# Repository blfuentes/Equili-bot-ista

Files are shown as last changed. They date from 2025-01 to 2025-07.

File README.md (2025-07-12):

# Project of Self-balancing bot 'Equili-bot-ista'
The 'Equili-bot-ista' / 'Roborracho' / 'Robotis Yeltsin' is a self-balancing robot which tries to keeb standing and can be controlled with a joystick control and wields a spear.

## Technologies
- ESP32 with ESP-IDF framework
- C++

## Functionalities
- Self balancing robot
- Two modes: Fighting and Footing (Spear position)
- Drive can be remotely controlled
- Adjustment of PID on the go with remote control

## Demo
### Robot

https://github.com/user-attachments/assets/f29adb14-0a24-4408-b29b-bd193cecef2e

### Control

https://github.com/user-attachments/assets/a7362dce-cef8-4407-b584-1fbcb6137070

## Media
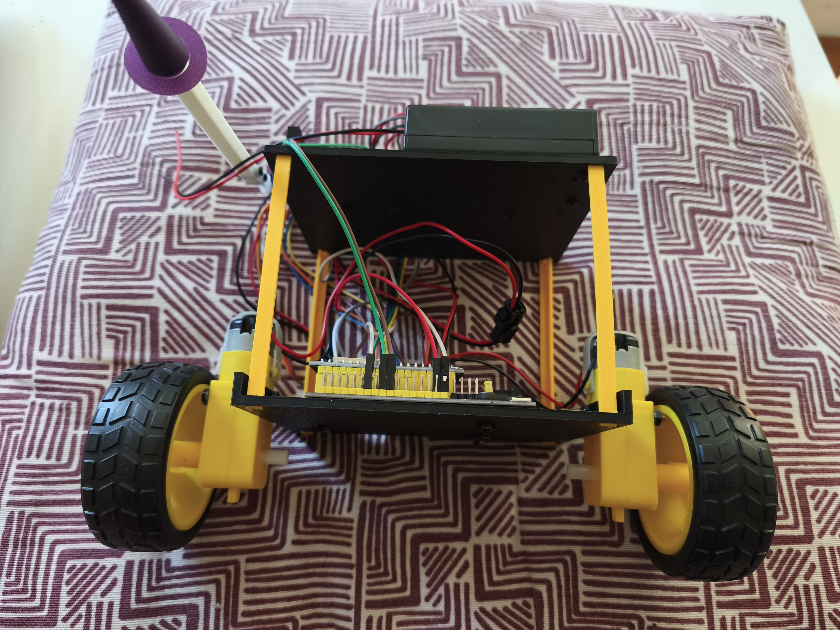
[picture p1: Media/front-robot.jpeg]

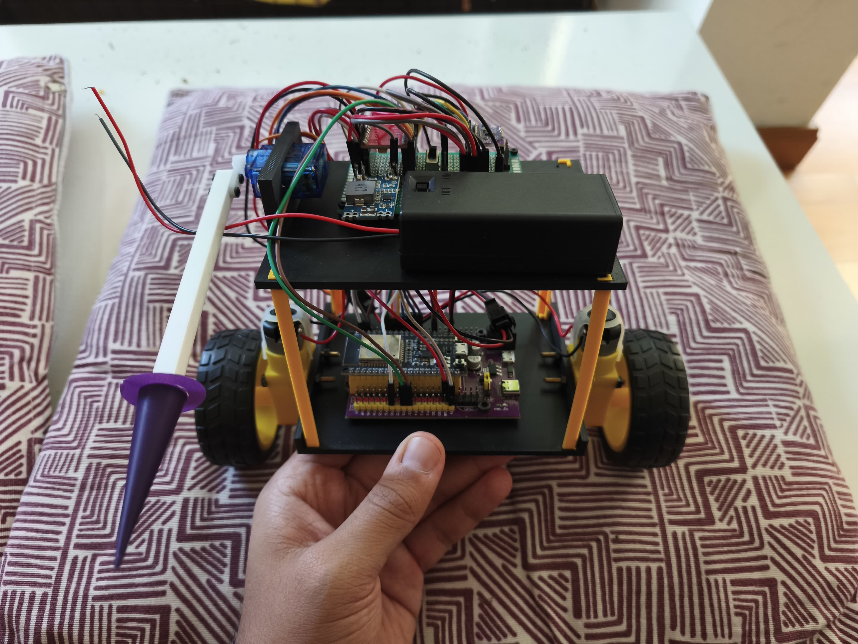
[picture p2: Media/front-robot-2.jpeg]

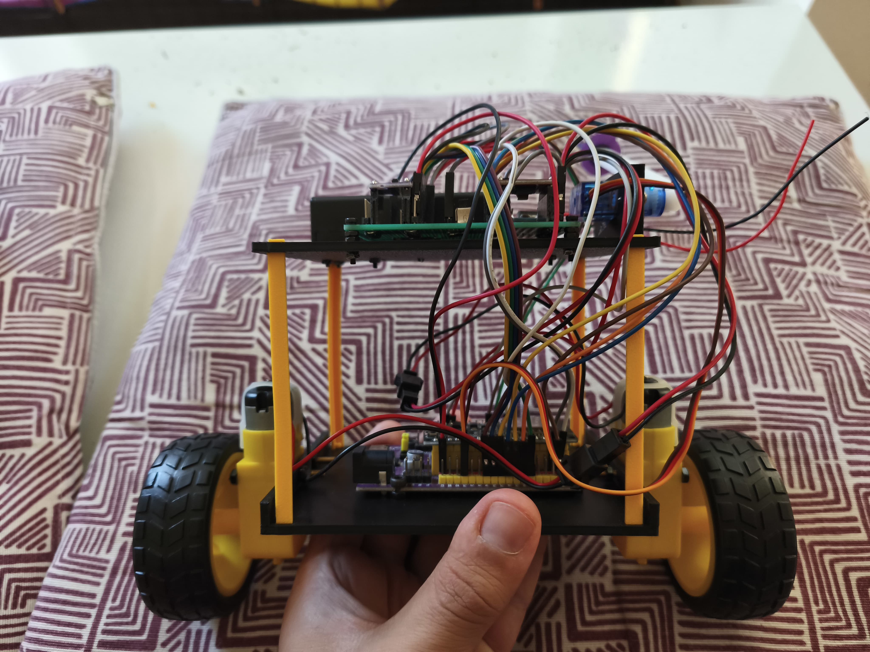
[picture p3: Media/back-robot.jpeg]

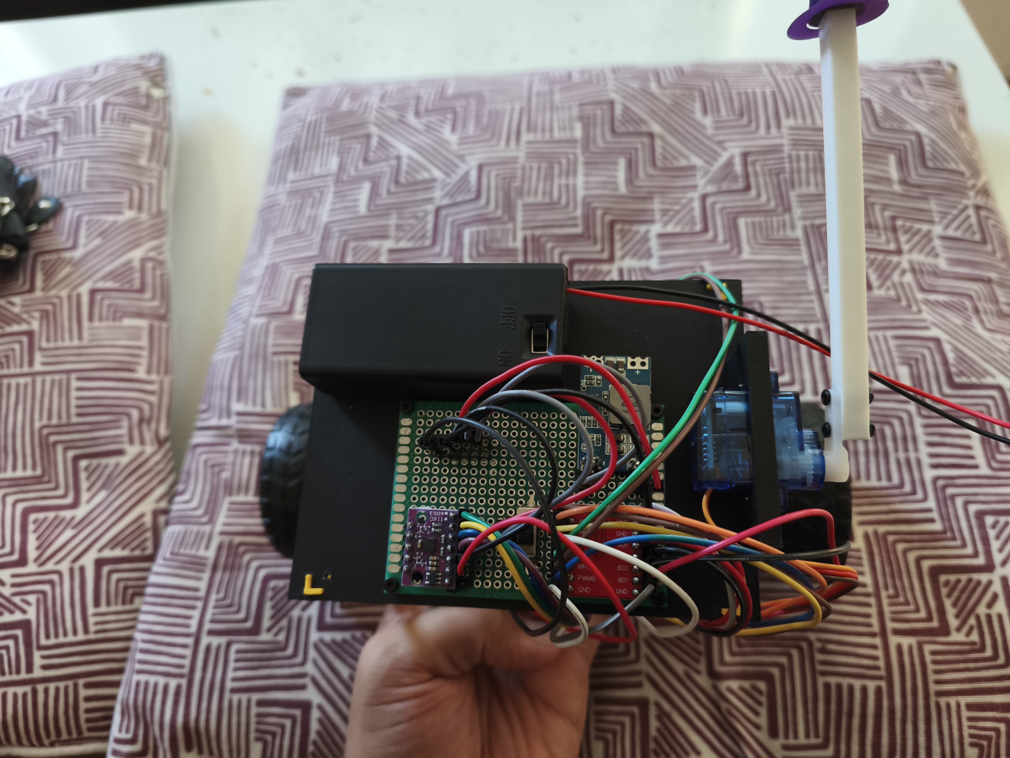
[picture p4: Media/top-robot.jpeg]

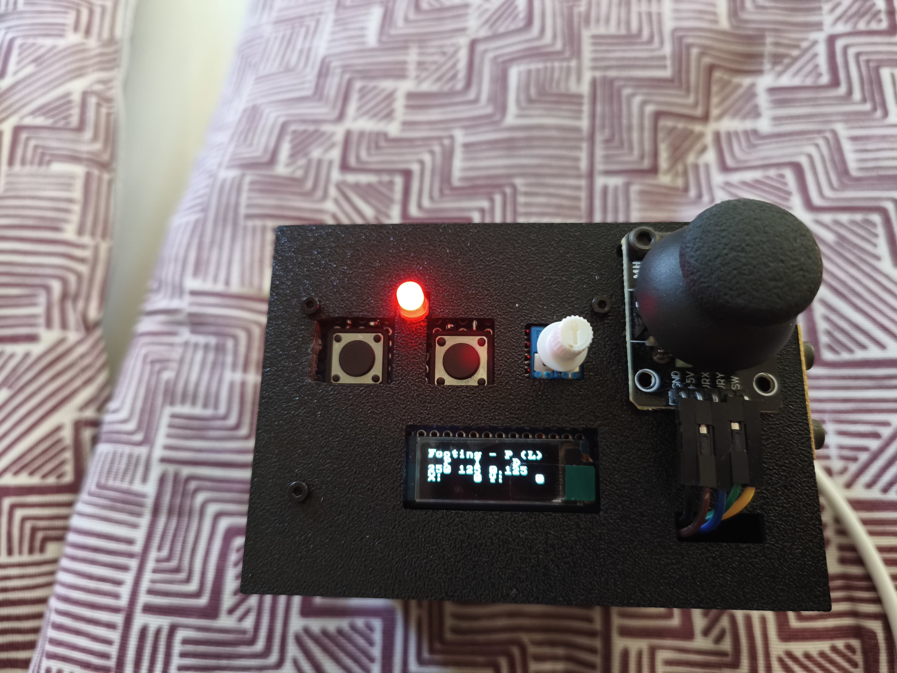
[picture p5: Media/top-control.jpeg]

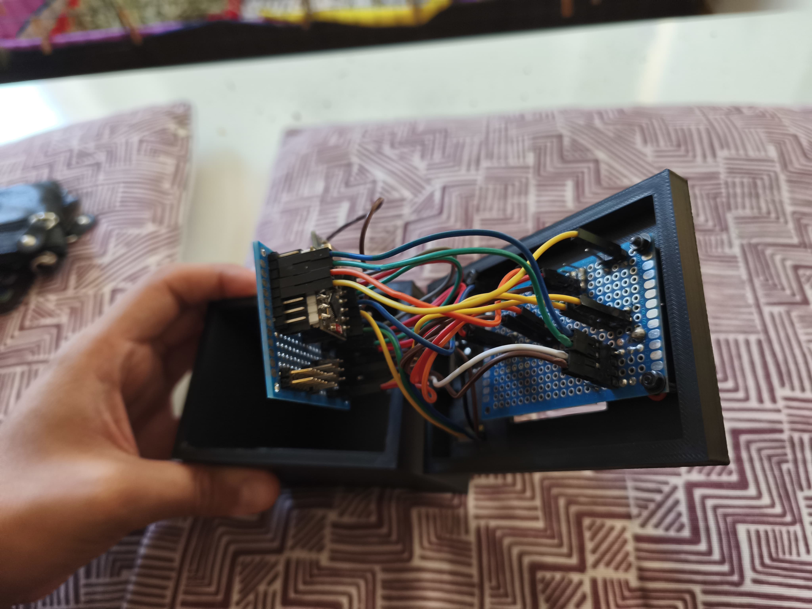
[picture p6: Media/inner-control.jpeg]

## Schema
### Main robot
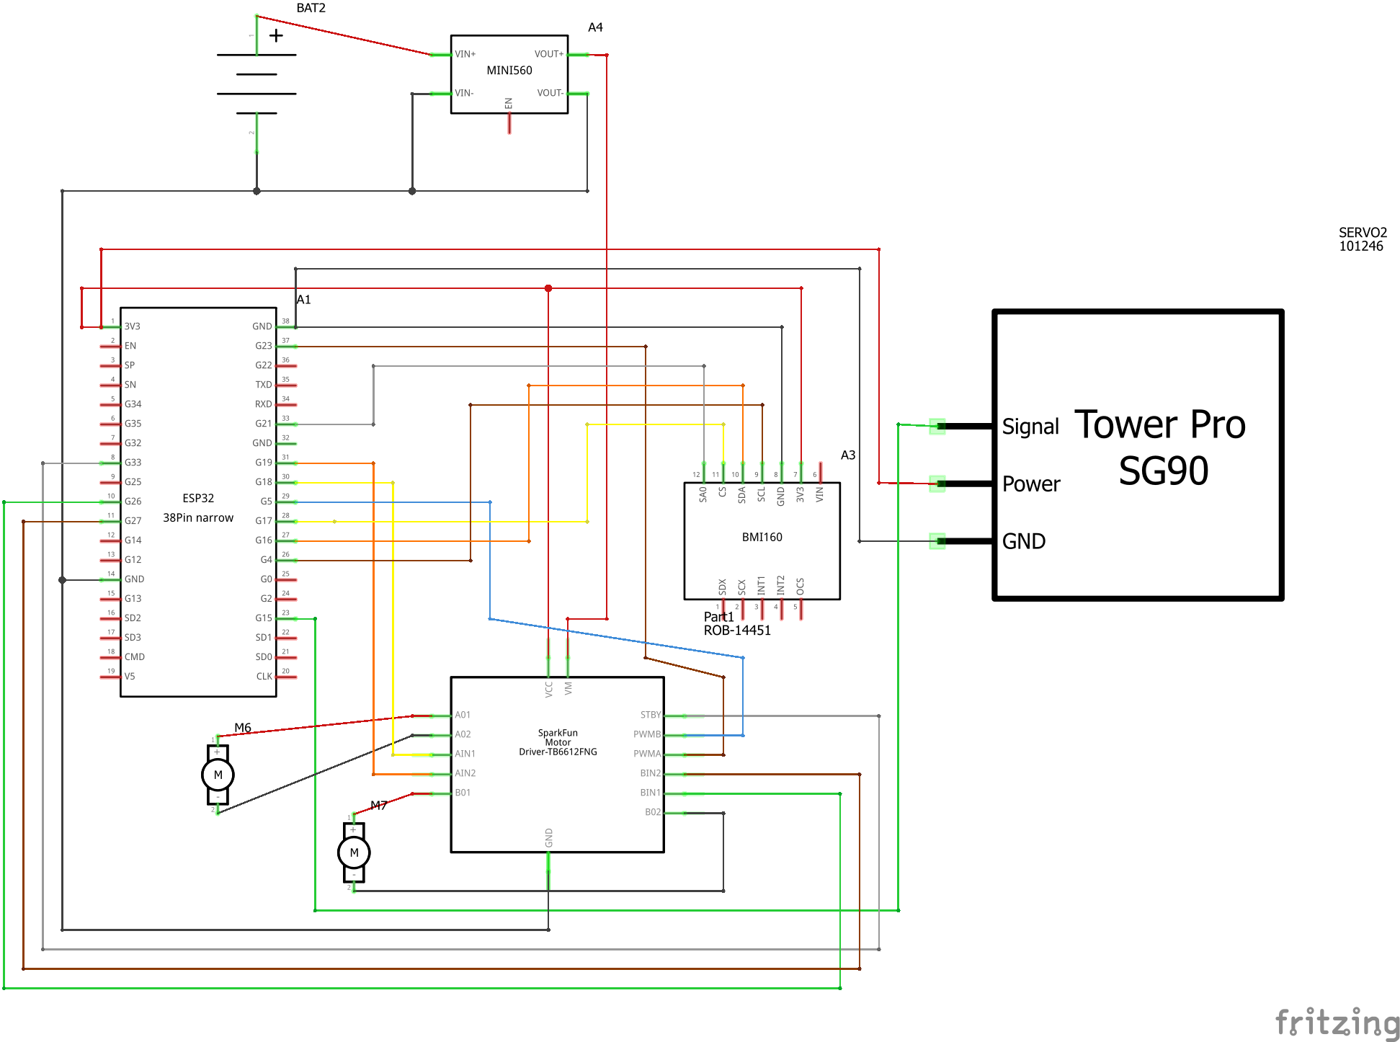
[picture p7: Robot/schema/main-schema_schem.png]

### Control
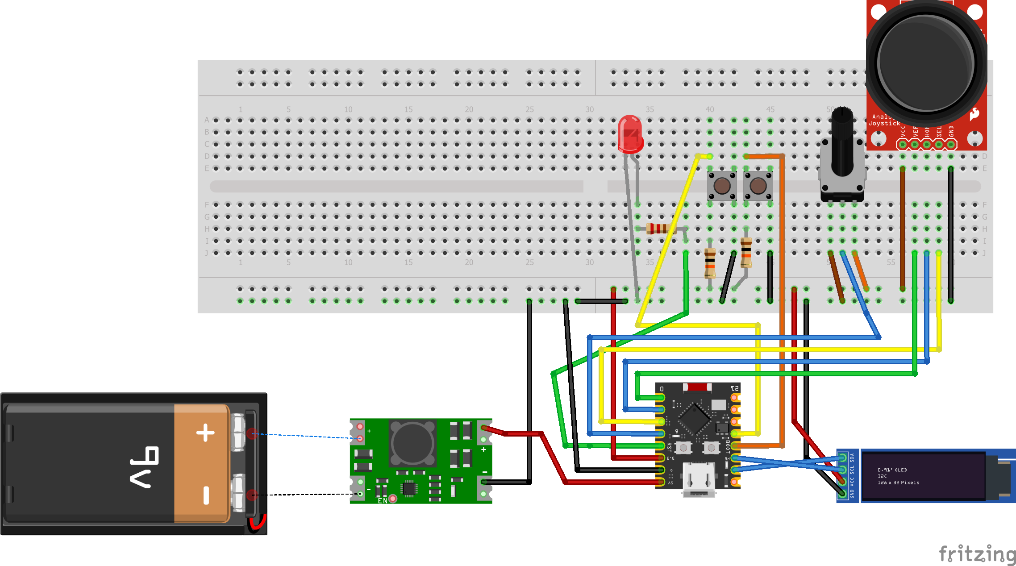
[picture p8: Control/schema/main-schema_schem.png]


## Class diagram
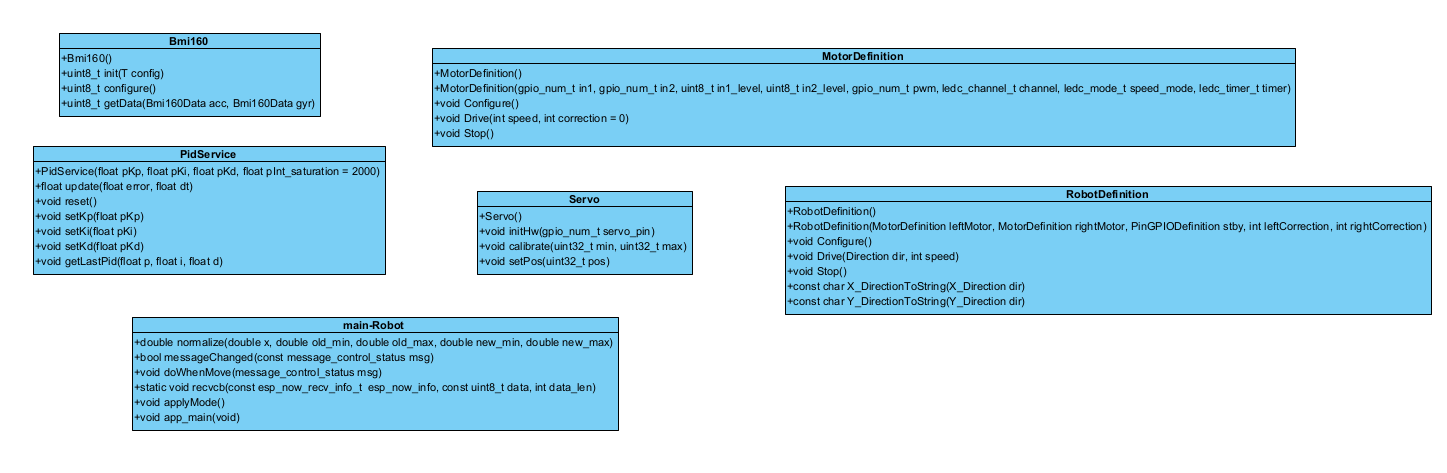
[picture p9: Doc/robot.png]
robot

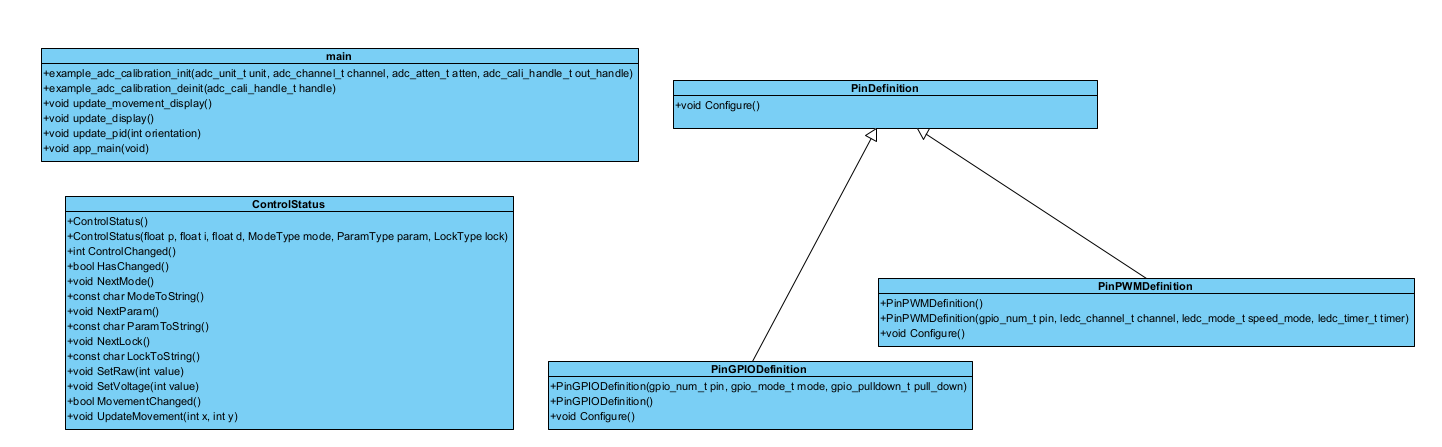
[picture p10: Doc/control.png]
control

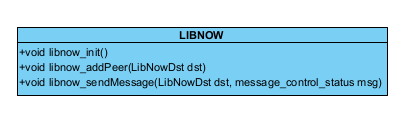
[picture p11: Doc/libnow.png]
libnow


Guided by:
https://github.com/LaboratorioGluon

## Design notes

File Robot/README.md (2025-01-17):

# Project of Self-balancing bot 'Equili-bot-ista'
## Technologies
- ESP32 with ESP-IDF framework
- C++

### Demo

### Schema
![]()
### Class diagram
![]()

Guided by:
https://github.com/LaboratorioGluon

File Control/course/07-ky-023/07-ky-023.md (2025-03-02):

```
#include <freertos/FreeRTOS.h>
#include <freertos/task.h>
#include <driver/gpio.h>
#include <driver/adc.h>
#include <esp_log.h>

// Logger tag for ESP-IDF logging
static const char * MAIN_TAG = "app_main";

extern "C" void app_main();

#define JOYSTICK_X ADC1_CHANNEL_6 // GPIO34
#define JOYSTICK_Y ADC1_CHANNEL_7 // GPIO35
#define BUTTON GPIO_NUM_32

void app_main(void)
{
    vTaskDelay(pdMS_TO_TICKS(1000));

    // Configure ADC
    esp_err_t ret;
    ret = adc1_config_width(ADC_WIDTH_BIT_12);
    if (ret != ESP_OK) {
        ESP_LOGE(MAIN_TAG, "Failed to configure ADC width: %s", esp_err_to_name(ret));
    }
    ret = adc1_config_channel_atten(JOYSTICK_X, ADC_ATTEN_DB_12);
    if (ret != ESP_OK) {
        ESP_LOGE(MAIN_TAG, "Failed to configure ADC channel X attenuation: %s", esp_err_to_name(ret));
    }
    ret = adc1_config_channel_atten(JOYSTICK_Y, ADC_ATTEN_DB_12);
    if (ret != ESP_OK) {
        ESP_LOGE(MAIN_TAG, "Failed to configure ADC channel Y attenuation: %s", esp_err_to_name(ret));
    }

    // Configure button with pull-down
    gpio_config_t io_conf;
    io_conf.intr_type = GPIO_INTR_DISABLE; // Disable interrupt
    io_conf.mode = GPIO_MODE_INPUT;       // Set as input
    io_conf.pin_bit_mask = (1ULL << BUTTON); // GPIO pin
    io_conf.pull_down_en = GPIO_PULLDOWN_DISABLE; // Disable pull-down
    io_conf.pull_up_en = GPIO_PULLUP_ENABLE;      // Enable pull-up
    ret = gpio_config(&io_conf);

    // Check if GPIO configuration was successful
    if (ret != ESP_OK) {
        ESP_LOGE(MAIN_TAG, "Failed to configure button GPIO: %s", esp_err_to_name(ret));
    } else {
        ESP_LOGI(MAIN_TAG, "Button GPIO configured successfully");
    }

    printf("KY-023 Joystick Test\n");

    for(;;)
    {
        int x_value = adc1_get_raw(JOYSTICK_X);
        int y_value = adc1_get_raw(JOYSTICK_Y);
        int button_state = gpio_get_level(BUTTON);
        printf("X: %d, Y: %d, Button: %d - %s\n", x_value, y_value, button_state, button_state ? "Not Pressed" : "Pressed");
        vTaskDelay(pdMS_TO_TICKS(100)); // Reduced delay for more responsive readings
    }
}
```

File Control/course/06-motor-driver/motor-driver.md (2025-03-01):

```
#include <freertos/FreeRTOS.h>
#include <freertos/task.h>
#include <driver/gpio.h>
#include <driver/ledc.h>
#include <esp_log.h>

#include <MotorControl.h>

// Logger tag for ESP-IDF logging
static const char * MAIN_TAG = "app_main";

// motor pins
constexpr gpio_num_t MOTOR_A_IN_1 = GPIO_NUM_18;
constexpr gpio_num_t MOTOR_A_IN_2 = GPIO_NUM_19;
constexpr gpio_num_t MOTOR_A_PWM = GPIO_NUM_23;

constexpr gpio_num_t MOTOR_B_IN_1 = GPIO_NUM_26;
constexpr gpio_num_t MOTOR_B_IN_2 = GPIO_NUM_27;
constexpr gpio_num_t MOTOR_B_PWM = GPIO_NUM_5;

constexpr gpio_num_t STBY = GPIO_NUM_33;

constexpr ledc_mode_t LEDC_SPEED_MODE = LEDC_LOW_SPEED_MODE;

MotorDefinition leftMotor;
MotorDefinition rightMotor;
PinGPIODefinition stby;

extern "C" void app_main();

void app_main(void)
{
    vTaskDelay(pdMS_TO_TICKS(1000));

    leftMotor = MotorDefinition(MOTOR_A_IN_1, MOTOR_A_IN_2, 0, 1, MOTOR_A_PWM, LEDC_CHANNEL_0, LEDC_SPEED_MODE, LEDC_TIMER_0);
    rightMotor = MotorDefinition(MOTOR_B_IN_1, MOTOR_B_IN_2, 1, 0, MOTOR_B_PWM, LEDC_CHANNEL_1, LEDC_SPEED_MODE, LEDC_TIMER_1);

    stby = PinGPIODefinition(STBY, GPIO_MODE_OUTPUT, GPIO_PULLDOWN_DISABLE);

    leftMotor.Configure();
    rightMotor.Configure();
    stby.Configure();

    gpio_set_level(STBY, 1);

    if (false)
    {
        ESP_LOGE(MAIN_TAG, "Failed to initialize bmi160 device");
    }
    else
    {
        for(;;)
        {
            leftMotor.Drive(100);
            vTaskDelay(pdMS_TO_TICKS(200));
            leftMotor.Stop();

            vTaskDelay(pdMS_TO_TICKS(1000));

            rightMotor.Drive(100);
            vTaskDelay(pdMS_TO_TICKS(200));
            rightMotor.Stop();
            
            vTaskDelay(pdMS_TO_TICKS(1000));
        }
    }
}

```

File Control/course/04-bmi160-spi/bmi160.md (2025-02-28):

```
#include <bmi160_wrapper.h>

Bmi160<Bmi160SpiConfig> imu;
gpio_num_t mosi_pin = GPIO_NUM_23;
gpio_num_t miso_pin = GPIO_NUM_19;
gpio_num_t sclk_pin = GPIO_NUM_18;
gpio_num_t cs_pin   = GPIO_NUM_21;

void app_main(void)
{
    Bmi160SpiConfig config = {
        .spidev = SPI3_HOST,
        .mosi = mosi_pin,
        .miso = miso_pin,
        .sclk = sclk_pin,
        .cs   = cs_pin,
        .speed= 4*1000*1000
    };

    if (imu.init(config) != BMI160_OK)
    {
        ESP_LOGE(MAIN_TAG, "Failed to initialize bmi160 device");
    }
    else
    {
        Bmi160Data accel_data, gyro_data;
        for(;;)
        {
            imu.getData(accel_data, gyro_data);

            printf("Raw-Accl: %6d %6d %6d\n", accel_data.raw_data.x, accel_data.raw_data.y, accel_data.raw_data.z);
            printf("Adj-Accl: %.2f %.2f %.2f\n", accel_data.adj_data.x, accel_data.adj_data.y, accel_data.adj_data.z);
            printf("Raw-Gyro: %6d %6d %6d\n", gyro_data.raw_data.x, gyro_data.raw_data.y, gyro_data.raw_data.z);
            printf("Adj-Gyro: %.2f %.2f %.2f\n", gyro_data.adj_data.x, gyro_data.adj_data.y, gyro_data.adj_data.z);

            vTaskDelay(pdMS_TO_TICKS(1000));
        }
    }
}
```

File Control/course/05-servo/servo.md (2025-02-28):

```
#include <servo.h>

Servo myServo;
gpio_num_t servo_pin = GPIO_NUM_15;

void app_main(void)
{
    vTaskDelay(pdMS_TO_TICKS(1000));

    myServo.initHw(servo_pin);
    uint32_t angle = 50;
    bool increasing = false;

    for(;;)
    {
        // Set the servo position
        myServo.setPos(angle);

        // Update the angle
        if (increasing) {
            angle++;
            if (angle >= 180) {
                increasing = false; // Reverse direction
            }
        } else {
            angle--;
            if (angle <= 0) {
                increasing = true; // Reverse direction
            }
        }

        vTaskDelay(pdMS_TO_TICKS(10));
    }
}
```

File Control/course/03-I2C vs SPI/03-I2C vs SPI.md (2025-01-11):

# I2C vs SPI

## Communication Type

| Feature | I2C | SPI |
|---|---|---|
| Type | Multi-master, multi-slave | Single-master or multi-slave |
| Connections | Two-wire (SDA, SCL) | Four-wire (MOSI, MISO, SCLK, CS) |

- I2C uses fewer pins, making it more suitable for simpler designs with |multiple devices on the same bus.
- SPI requires more pins but offers higher performance.

## Speed

|Feature | I2C | SPI |
|---|---|---|
|Typical Speed | Up to 400 kHz (standard mode), 3.4 MHz (high-speed mode) | Up to 80 MHz (ESP32 supports high clock speeds) |

- I2C is slower, making it suitable for low-speed peripherals like sensors.
- SPI is significantly faster, ideal for high-speed peripherals like displays or memory chips.

## Data Transfer
|Feature | I2C | SPI
|---|---|---|
|Data Transfer | Half-duplex | Full-duplex |

- I2C is half-duplex, meaning data transfer occurs in one direction at a time.
- SPI supports full-duplex communication, enabling simultaneous data transfer in both directions.

## Device Addressing

| Feature | I2C | SPI |
|---|---|---|
|Device Selection | Uses 7-bit or 10-bit addresses | Uses chip select (CS) lines |

- I2C relies on device addresses for communication, so fewer pins are required.
- SPI uses dedicated CS lines, requiring one CS pin per device.

## Power Consumption
| Feature | I2C | SPI |
|---|---|---|
| Power Usage | Lower (less active circuitry) | Higher (higher clock rates) |

- I2C typically consumes less power due to lower speeds.
- SPI may consume more power at high speeds but allows more efficient data transfer.

## Complexity

| Feature | I2C | SPI |
|---|---|---|
| Complexity | Simpler to wire, but requires software handling for addressing and bus arbitration | More pins and wiring complexity but straightforward data transfer protocol |

## Use Cases
| Feature | I2C | SPI |
|---|---|---|
| Best For | Low-speed devices like sensors, RTCs, small EEPROMs | High-speed devices like LCDs, flash memory, ADCs, DACs |

## Summary Table
| Feature | I2C | SPI |
|---|---|---|
| Pins Required | 2 | 4 (minimum) |
| Speed | Slower | Faster |
| Duplex | Half-duplex | Full-duplex |
| Device Count | Many devices (addressable) | Limited by CS pins |
| Best For | Low-speed peripherals | High-speed peripherals |

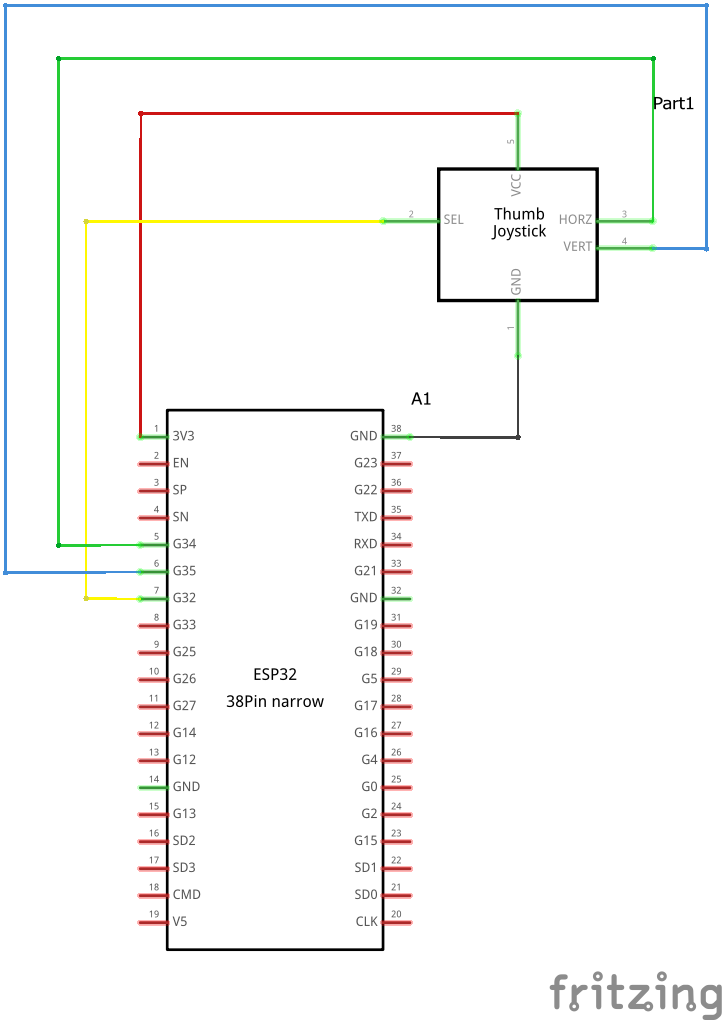
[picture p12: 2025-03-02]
Control/course/07-ky-023/schema/07-ky-023_schem.png

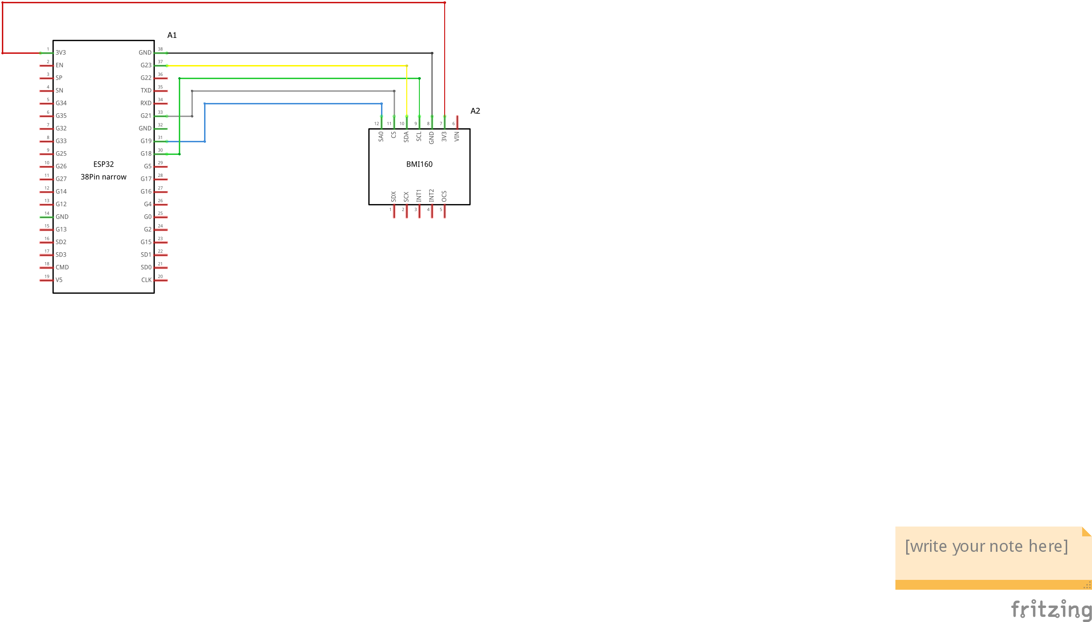
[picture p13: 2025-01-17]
Robot/course/04-bmi160-spi/Schema/04-bmi16-schema_schem.png

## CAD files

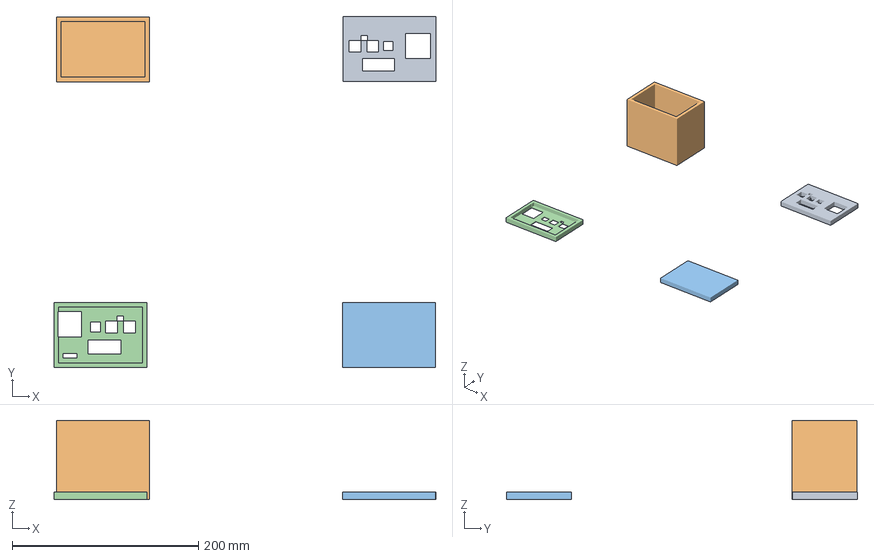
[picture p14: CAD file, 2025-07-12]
3D-Chase/Control.3mf
410.6 x 377.7 x 85.0 mm
Assembly

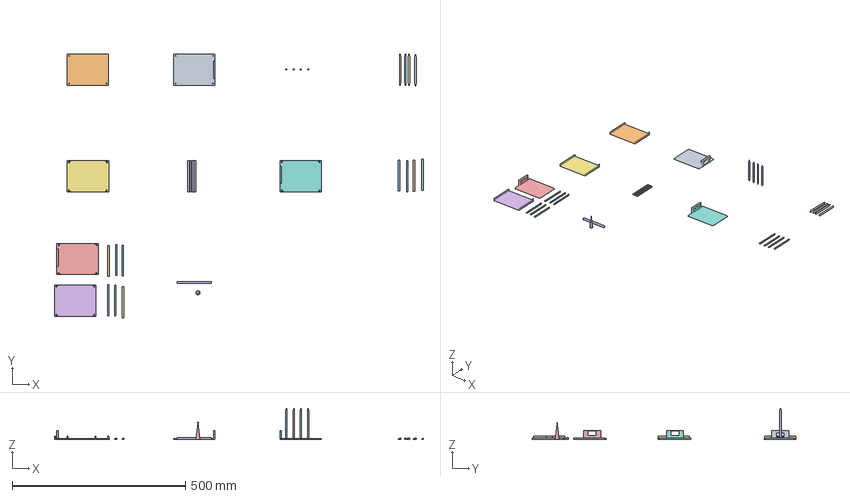
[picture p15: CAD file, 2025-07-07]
3D-Chase/Equili-bot-ista.3mf
1064.5 x 761.1 x 90.0 mm
Top
Base
Assembly x 18

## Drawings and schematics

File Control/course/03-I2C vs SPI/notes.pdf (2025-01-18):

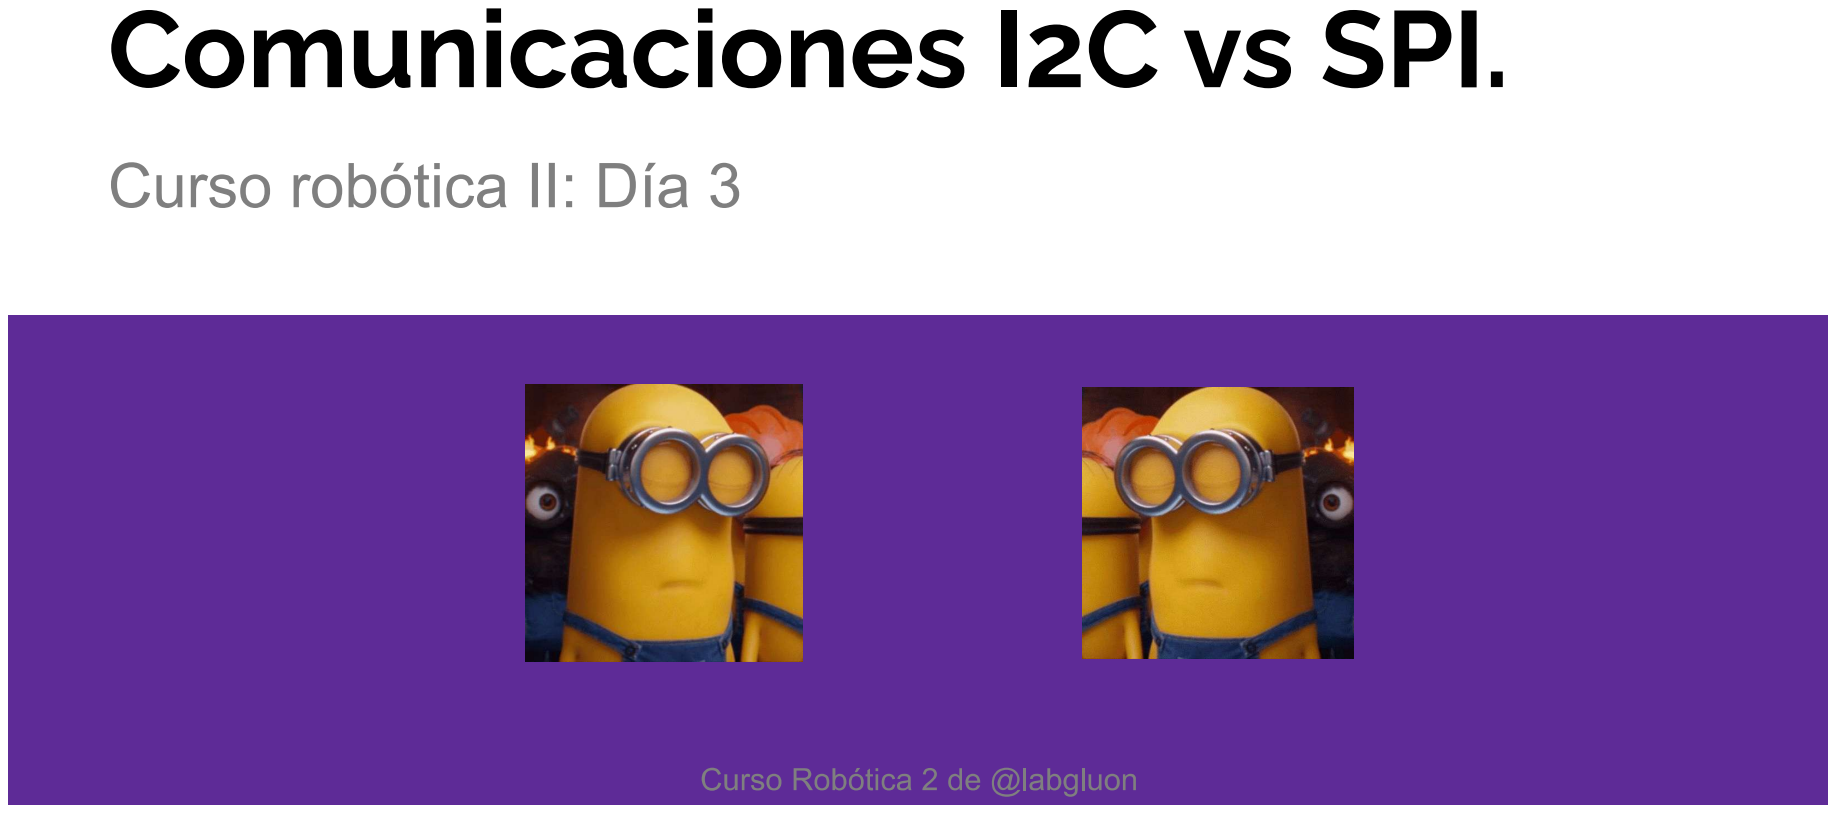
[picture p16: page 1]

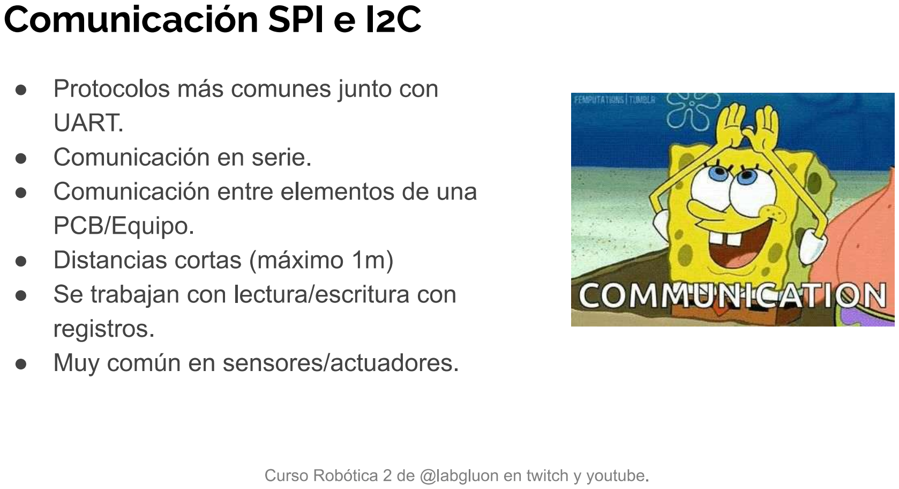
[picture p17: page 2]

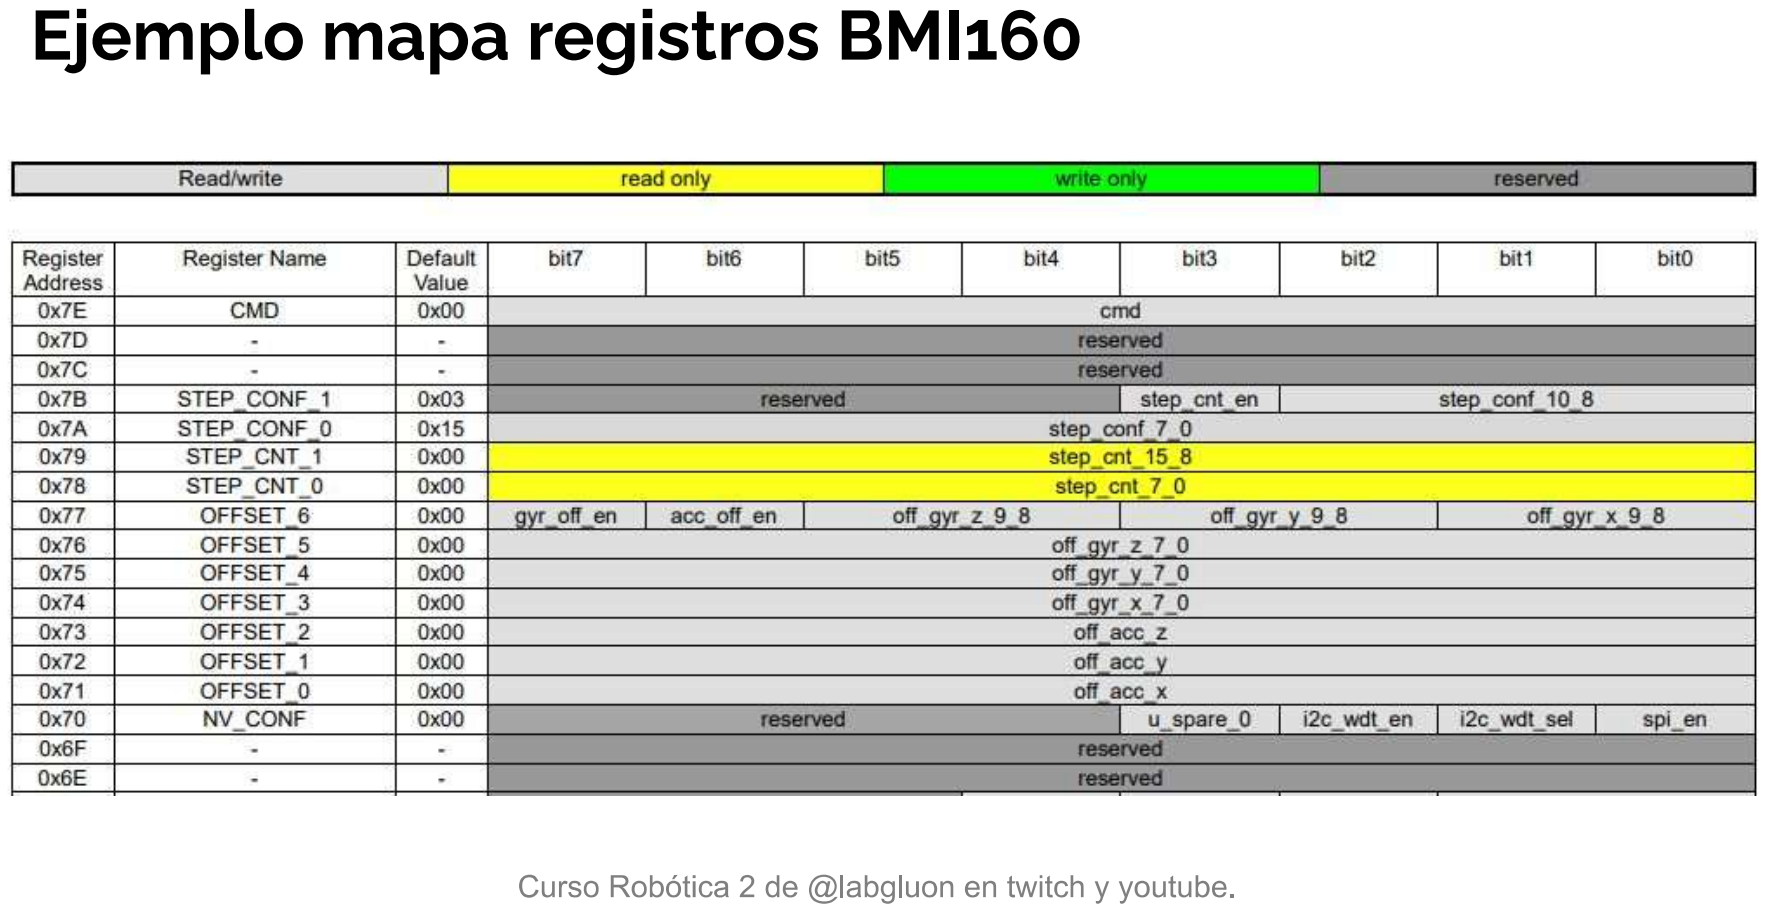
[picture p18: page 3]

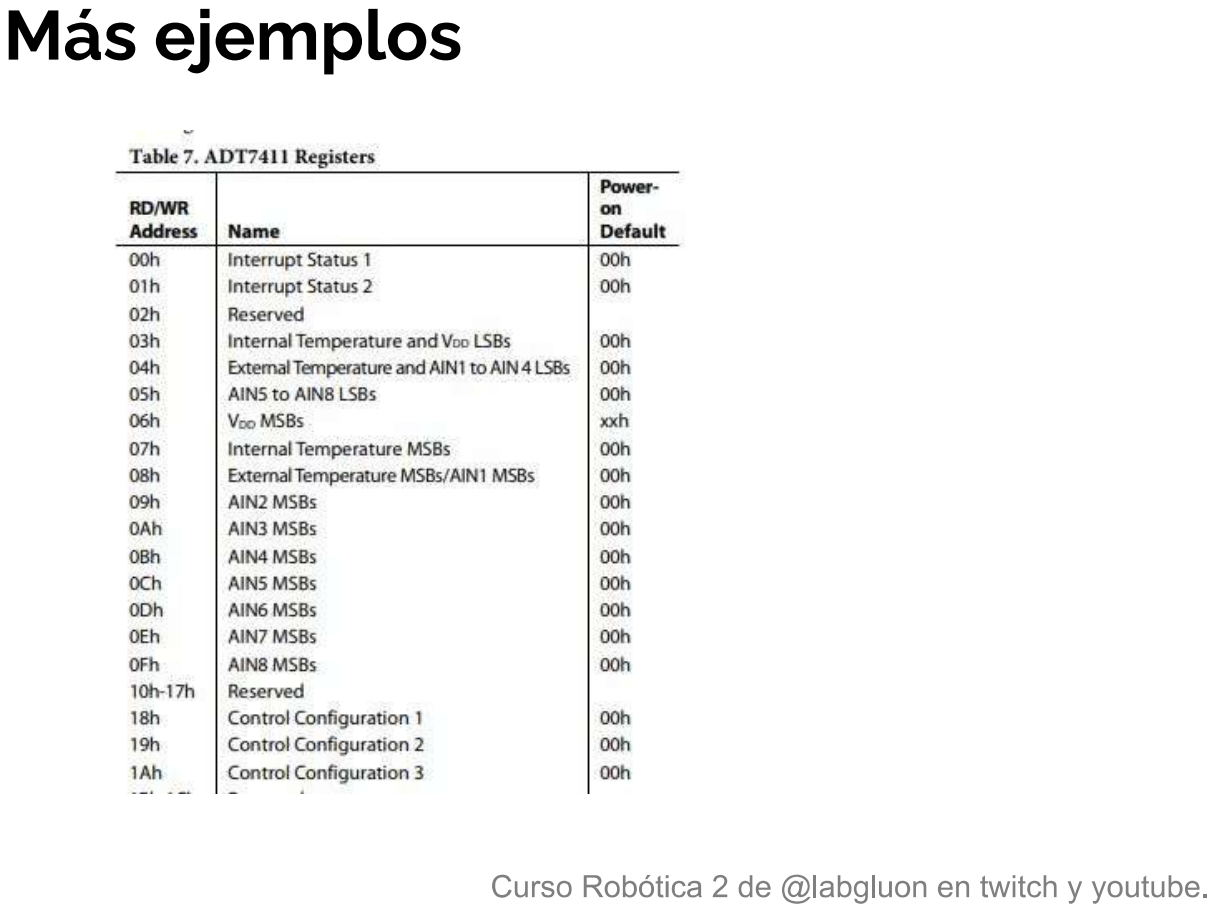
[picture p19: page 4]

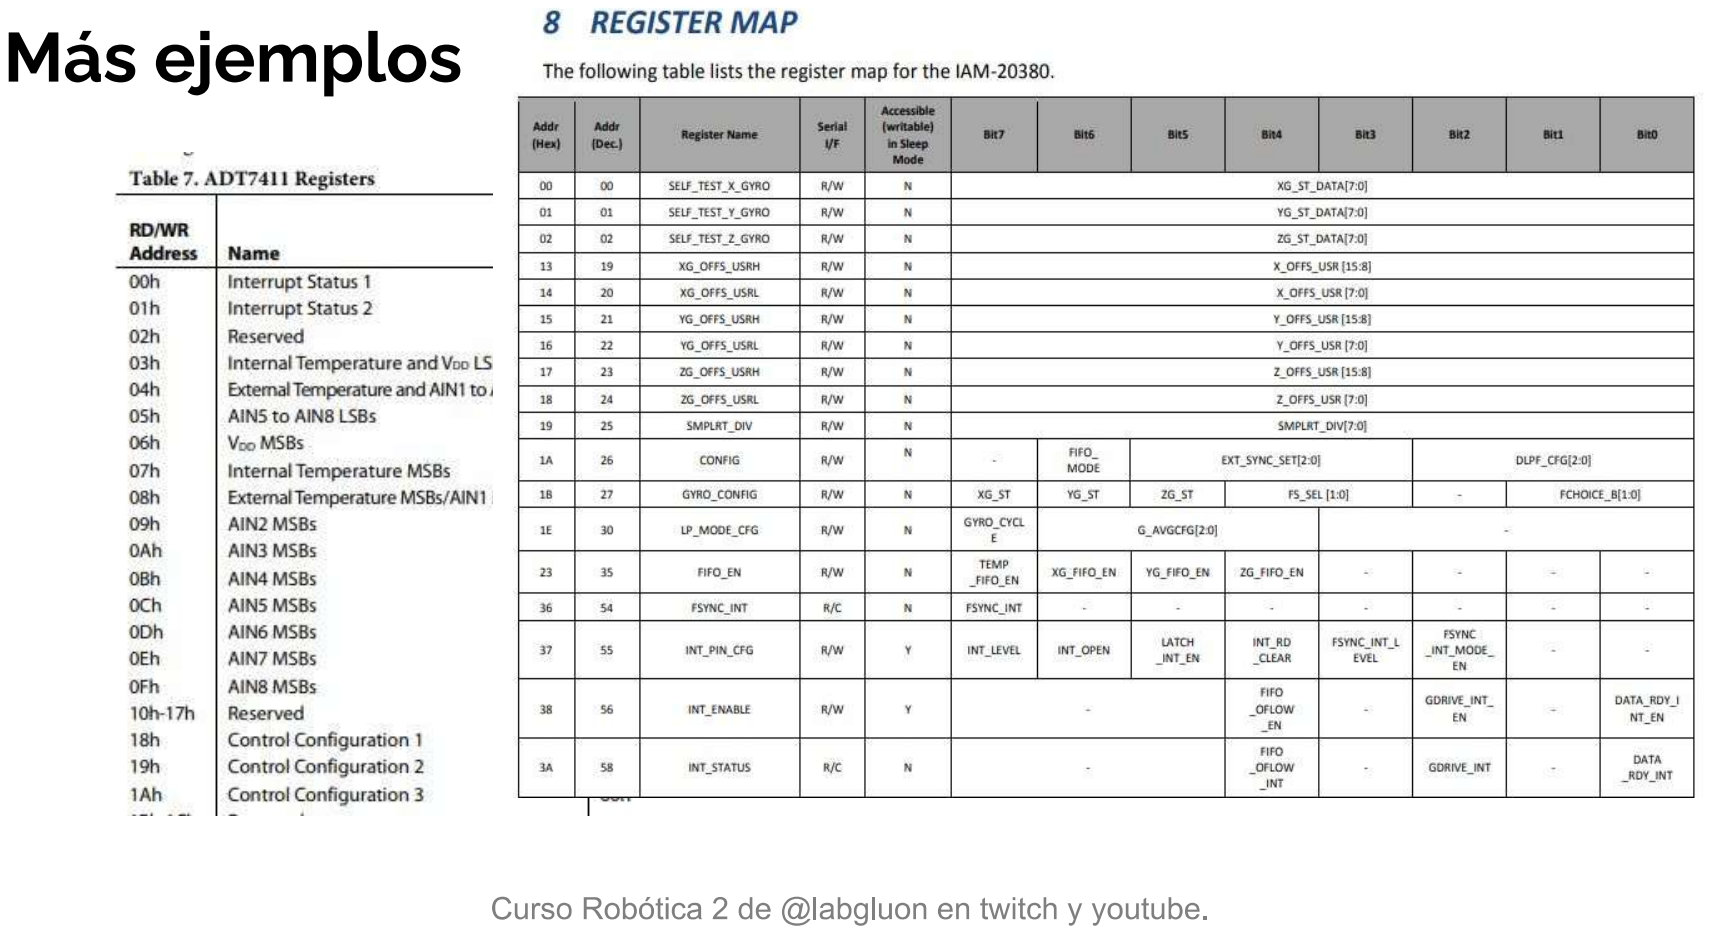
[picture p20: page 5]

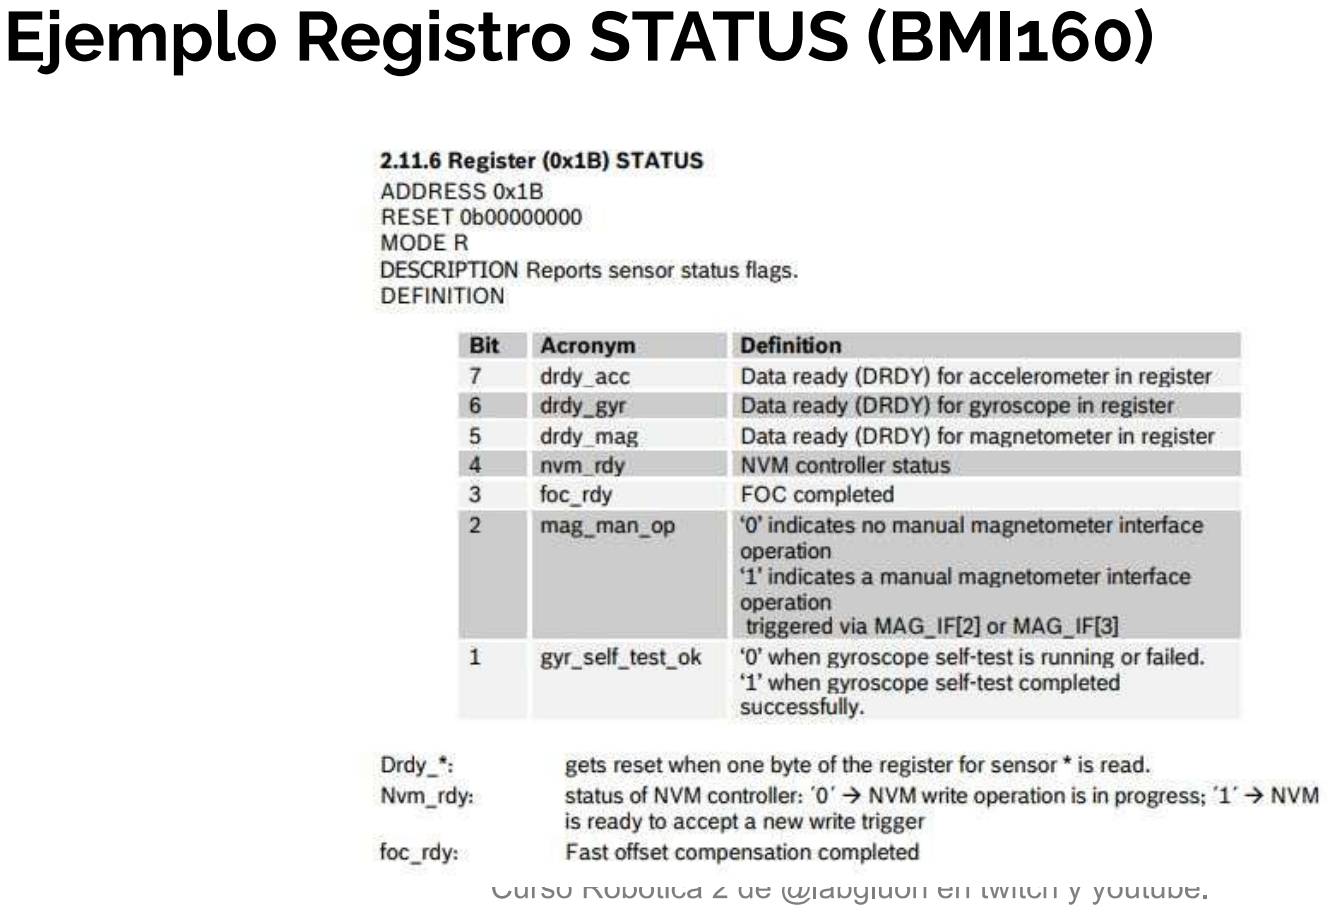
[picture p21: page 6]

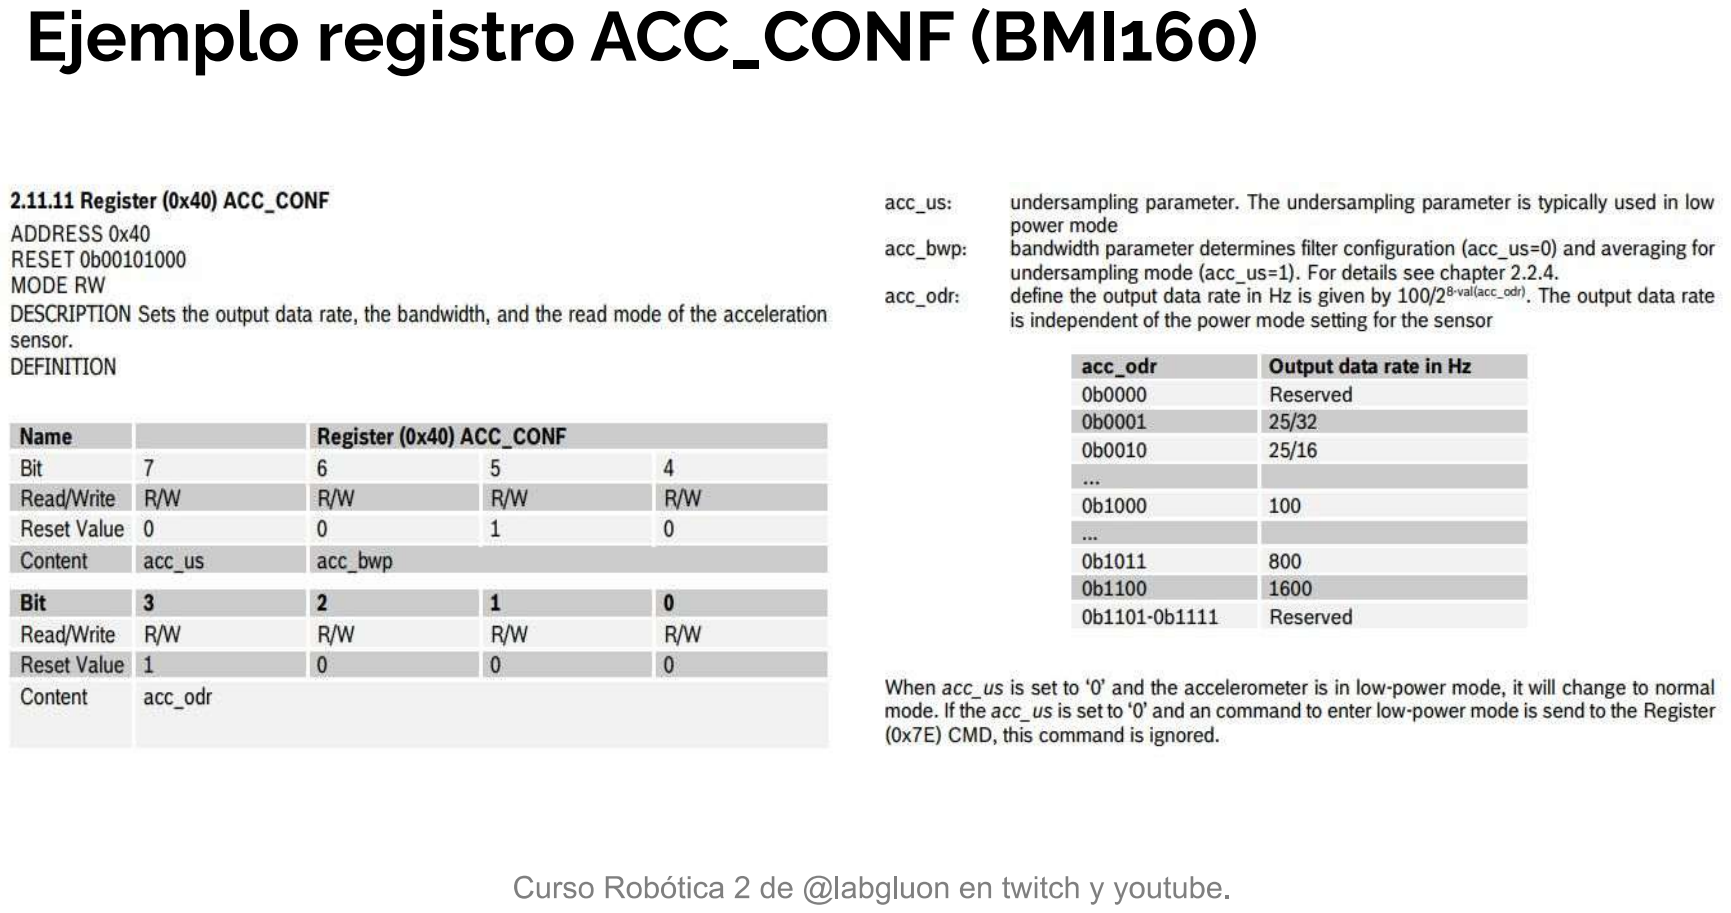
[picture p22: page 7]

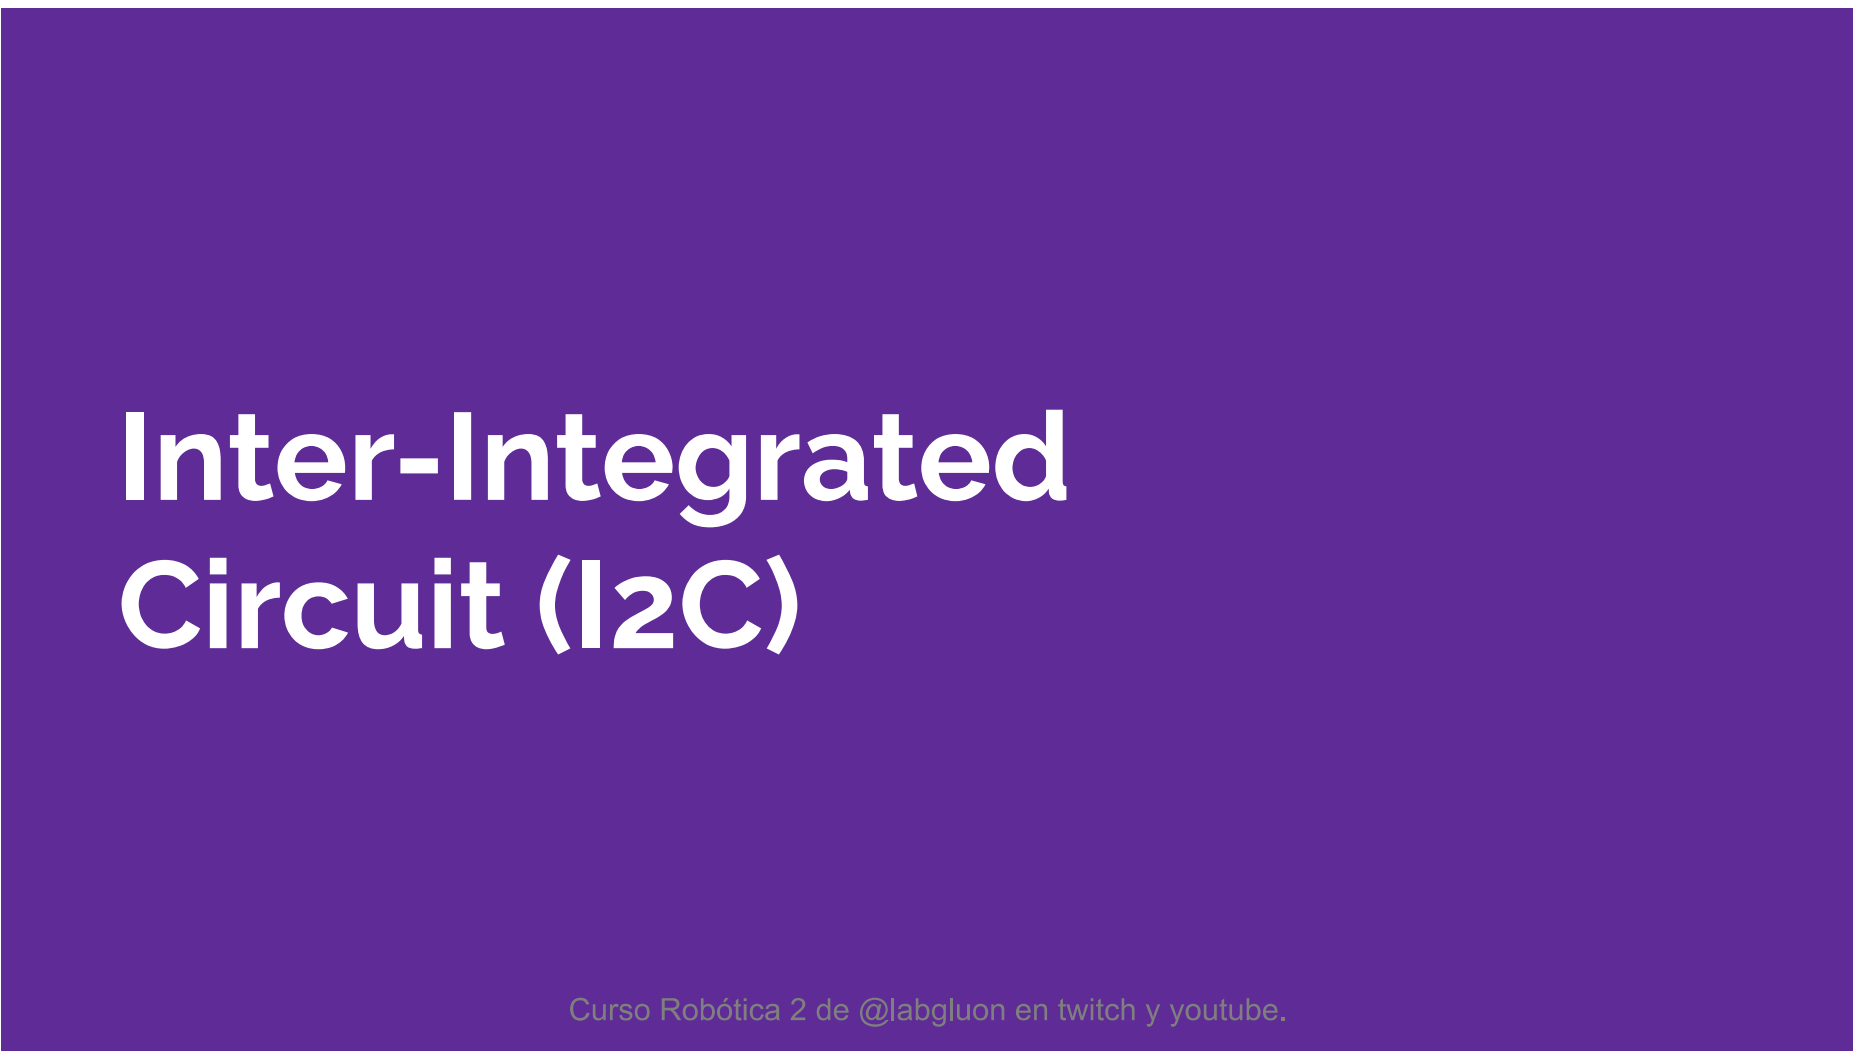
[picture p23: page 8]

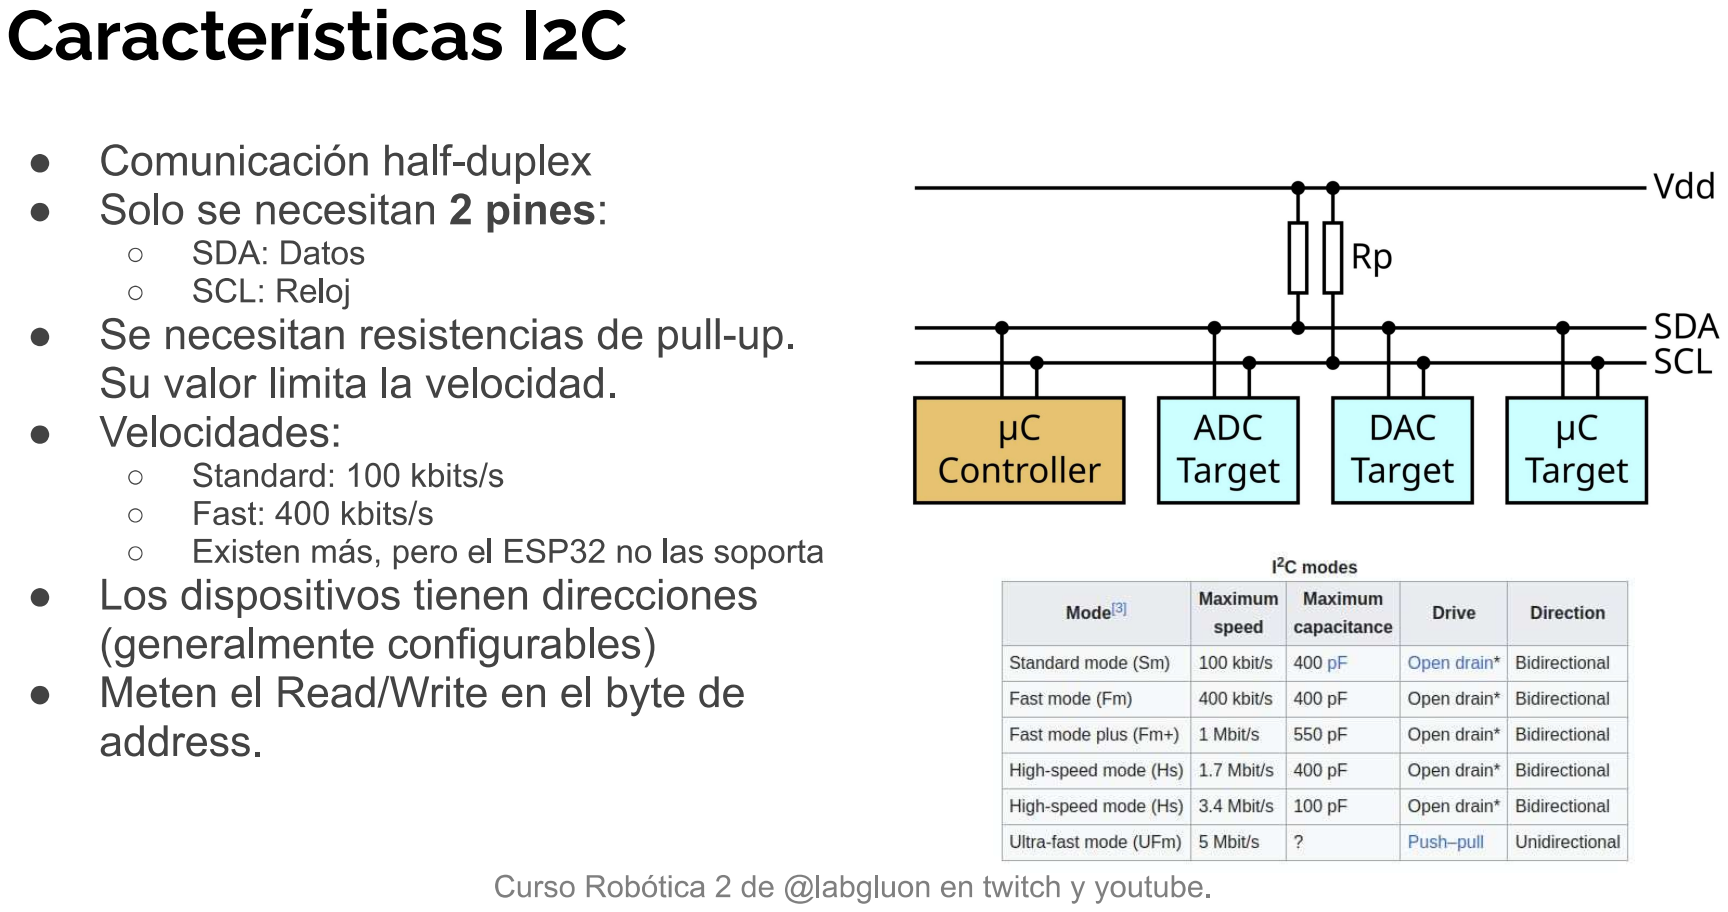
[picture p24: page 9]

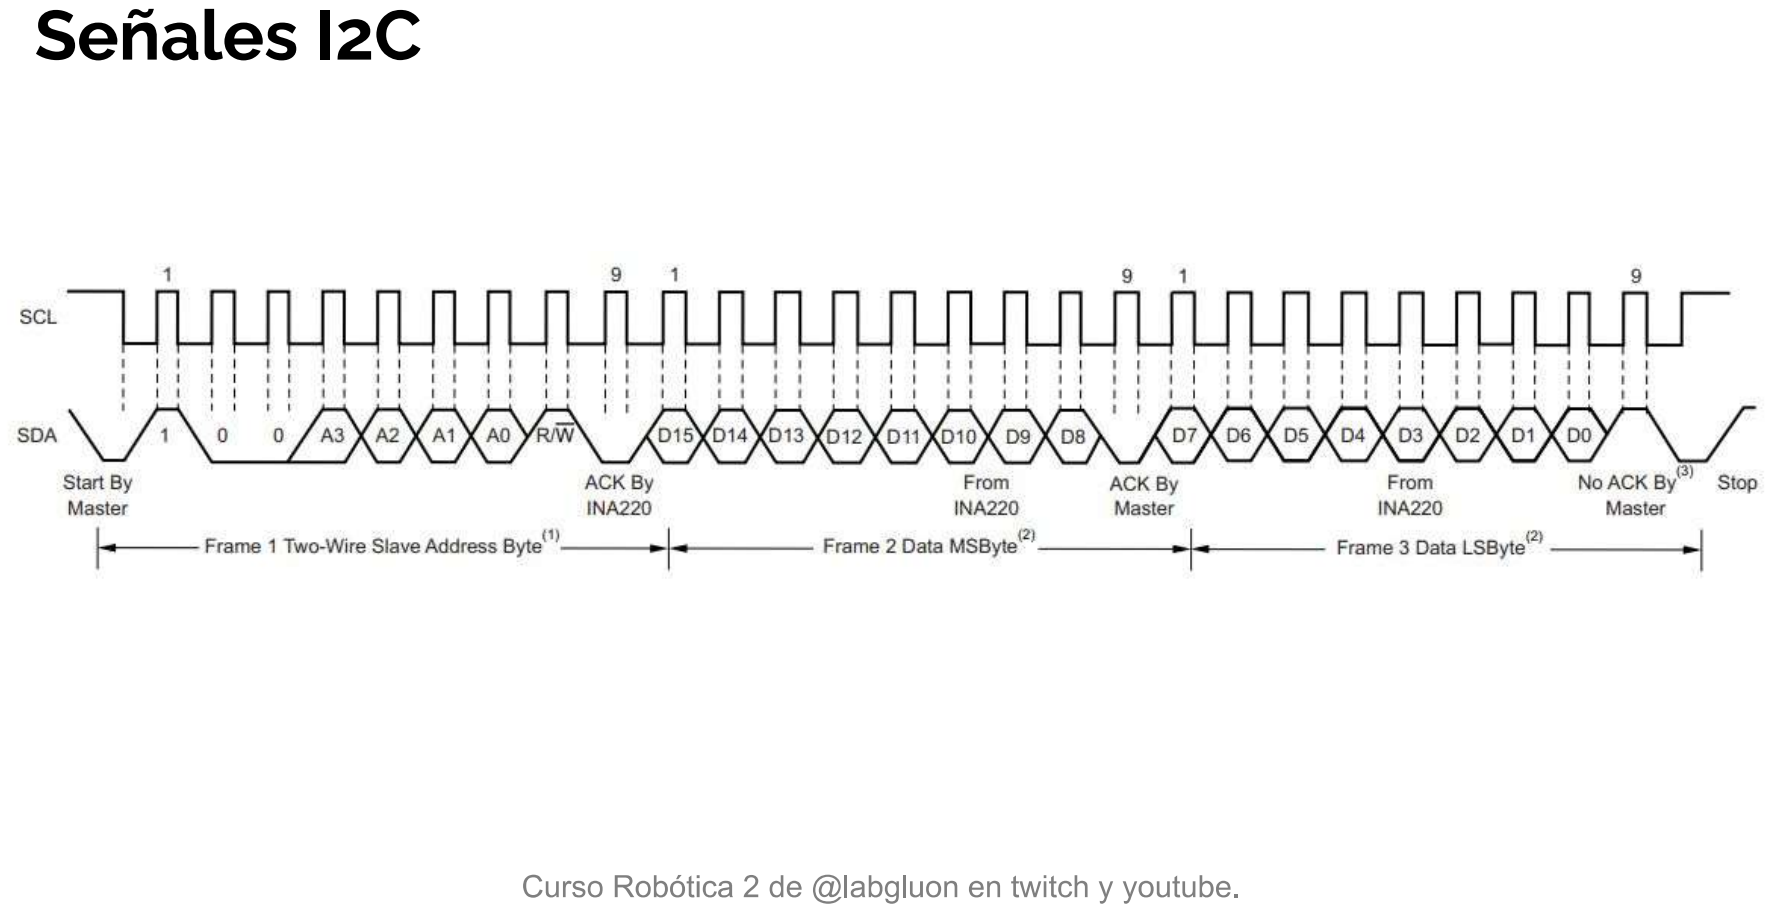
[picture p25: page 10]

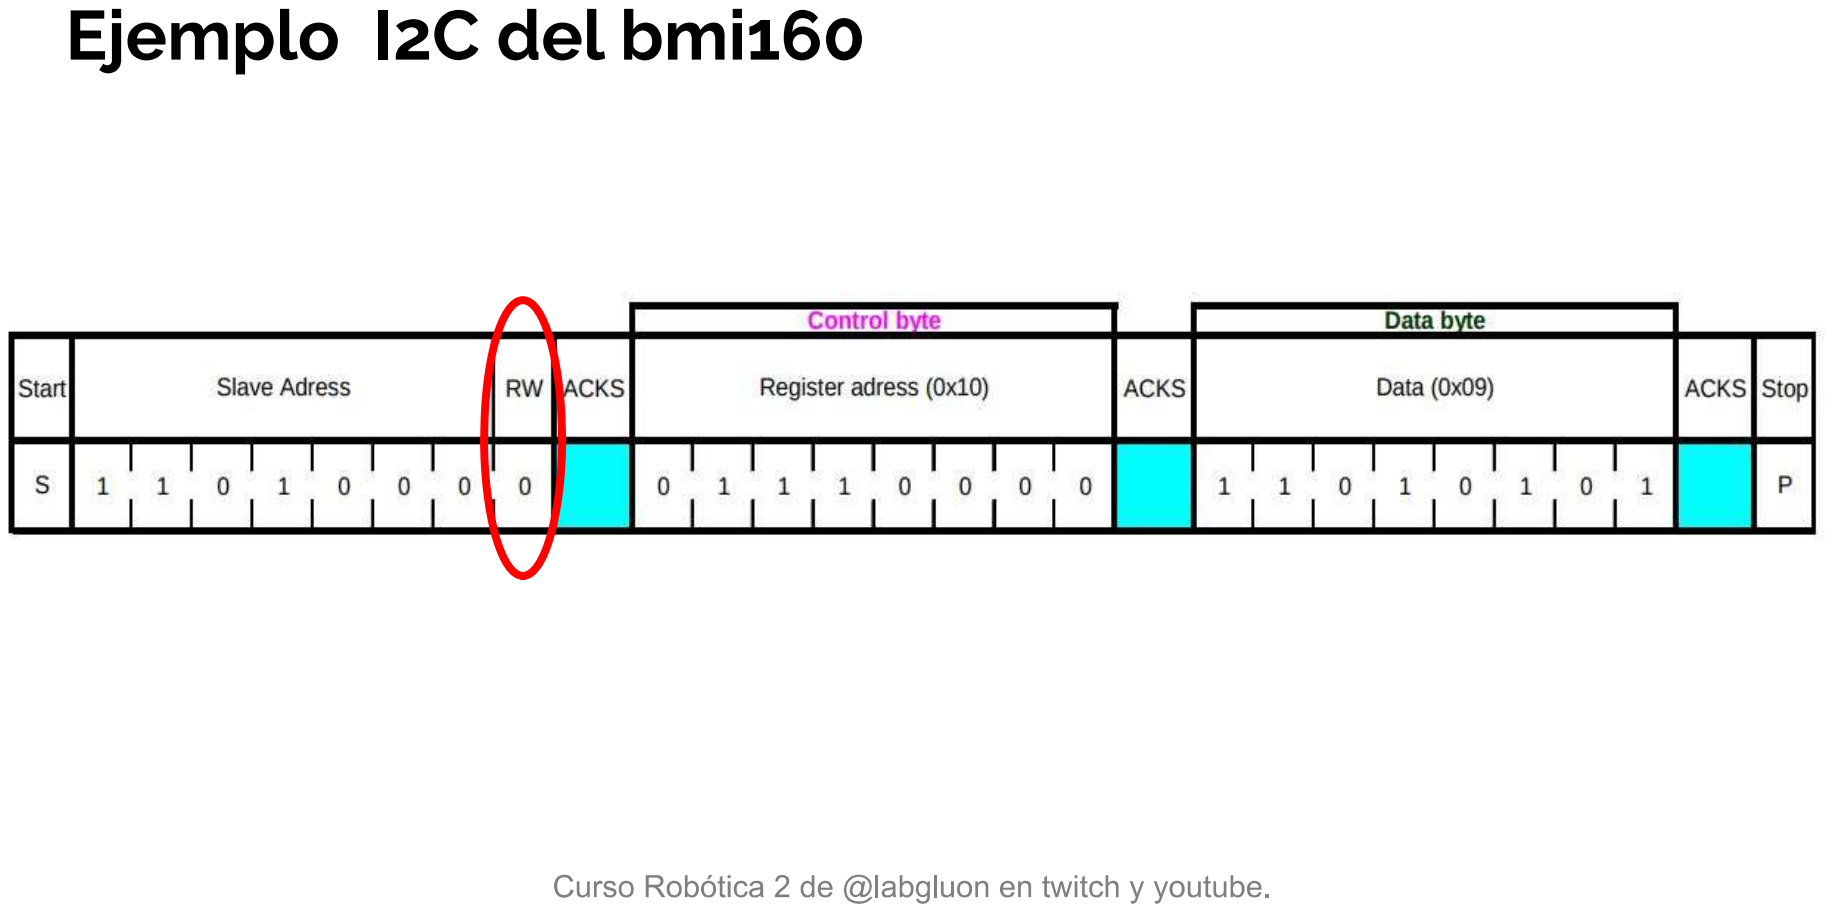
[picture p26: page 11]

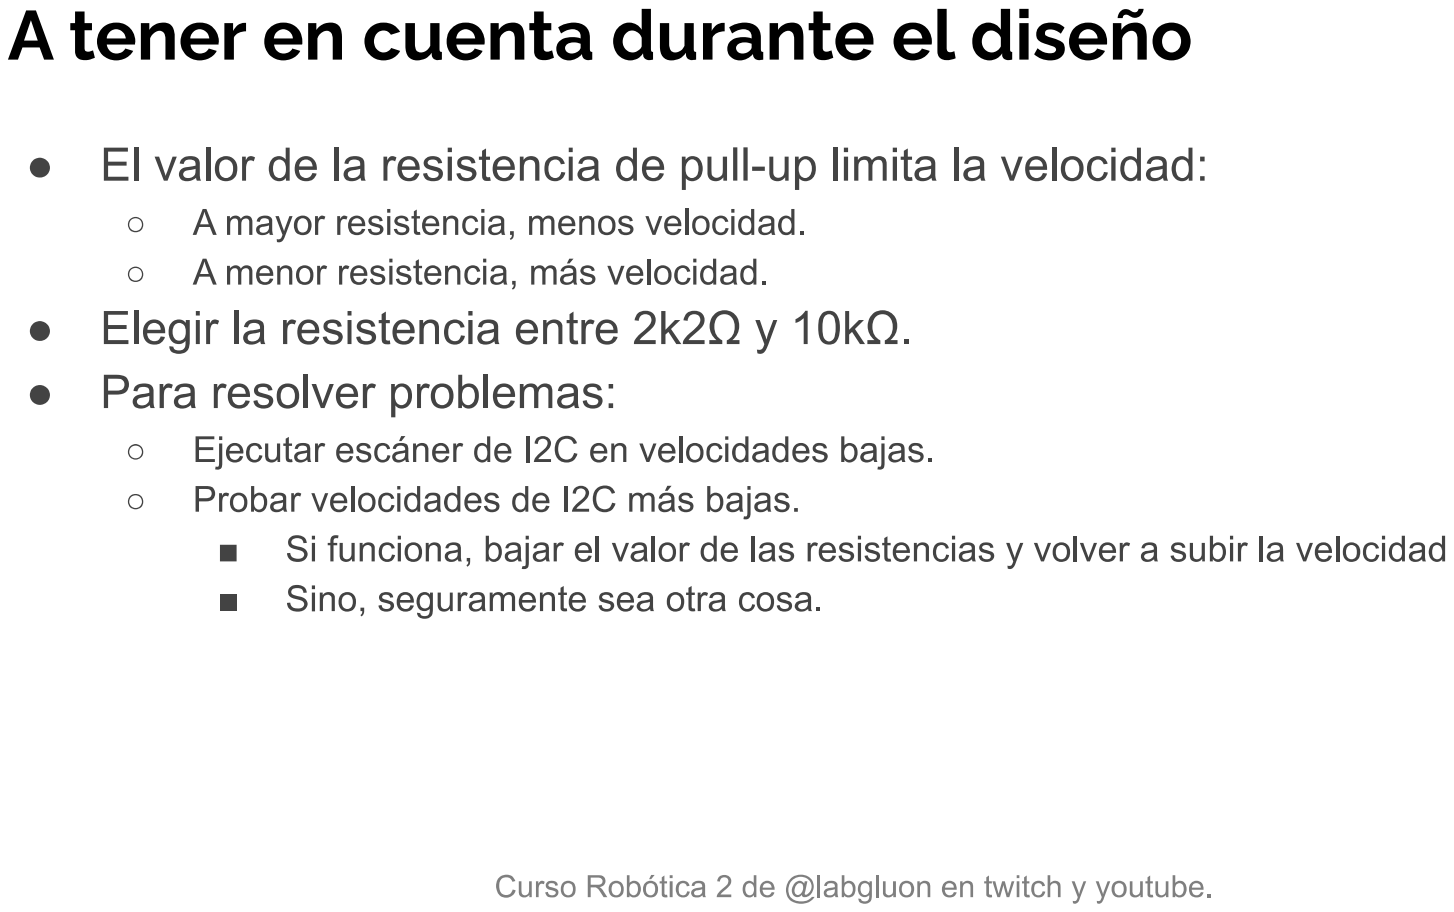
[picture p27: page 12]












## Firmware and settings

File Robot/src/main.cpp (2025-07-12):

#include <freertos/FreeRTOS.h>
#include <freertos/task.h>
#include <driver/gpio.h>
#include <driver/ledc.h>
#include <esp_log.h>
#include <esp_now.h>
#include <esp_timer.h>

#include "libnow.h"

#include "MotorControl.h"
#include "bmi160_wrapper.h"
#include "PIDService.h"
#include "RobotControl.h"
#include "servo.h"

// Libnow
#define MAC_ROBOT { 0xd8, 0xbc, 0x38, 0xf9, 0x3b, 0x4c }

// Logger tag for ESP-IDF logging
static const char *MAIN_TAG = "main_log";
static const char *MOTOR_TAG = "motor_log";
static const char *IMU_TAG = "imu_log";
static const char *ACTION_TAG = "action_log";
static const char *LIBNOW_TAG = "libnow_log";
static const char *MESSAGE_TAG = "message_log";
static const char *CONTROL_TAG = "control_log";
static const char *SERVO_TAG = "servo_log";

// motor pins
constexpr gpio_num_t MOTOR_A_IN_1 = GPIO_NUM_18;
constexpr gpio_num_t MOTOR_A_IN_2 = GPIO_NUM_19;
constexpr gpio_num_t MOTOR_A_PWM = GPIO_NUM_23;

constexpr gpio_num_t MOTOR_B_IN_1 = GPIO_NUM_26;
constexpr gpio_num_t MOTOR_B_IN_2 = GPIO_NUM_27;
constexpr gpio_num_t MOTOR_B_PWM = GPIO_NUM_5;

constexpr gpio_num_t STBY = GPIO_NUM_33;

constexpr ledc_mode_t LEDC_SPEED_MODE = LEDC_LOW_SPEED_MODE;

RobotDefinition robot;  
static const int LEFT_MOTOR_CORRECTION = 25; // Correction for left motor
static const int RIGHT_MOTOR_CORRECTION = 0; // Correction for right motor
static const int BASE_SPEED = 350; // Default speed for motors
static const float MAX_CONTROL_RANGE = 1800.0f; // Maximum control range for control inputs
static const int MIN_MOVE_X = -2130; // Minimum value for move_x
static const int MAX_MOVE_X = 1956; // Maximum value for move_x
static const int MIN_MOVE_Y = -2180; // Minimum value for move_y
static const int MAX_MOVE_Y = 1911; // Maximum value for move_y
static const float DELTA_FORWARD_ALPHA_RANGE = 3.45f;
static const float DELTA_BACKWARD_ALPHA_RANGE = 2.50f;
static const float TURN_RANGE = 620.0f;
static const float CONTROL_THRESHOLD = .1f; // Threshold for control input to be considered significant

float deltaAlpha = 0.0f;
float turn = 0.0f;

//
float initAccelYCorrection = 0.020020f; // Correction for initial acceleration on Y axis
float initAccelZCorrection = 0.982452f; // Correction for initial acceleration on Z axis
float expectedVerticalWarmode = 91.7f; //alpha in war mode
float expectedVerticalStandingmode = 93.0f; //alpha in standing mode
float expected_vertical = 88.5;

// bmi
Bmi160<Bmi160SpiConfig> imu;
gpio_num_t MOSI_PIN = GPIO_NUM_16;
gpio_num_t MISO_PIN = GPIO_NUM_21;
gpio_num_t SCLK_PIN = GPIO_NUM_4;
gpio_num_t CS_PIN   = GPIO_NUM_17;

// Servo
Servo servo;
gpio_num_t servo_pin = GPIO_NUM_15;

// PID
constexpr float PID_KP = 250.0f; // Proportional gain
constexpr float PID_KI = 150.0f; // Integral gain
constexpr float PID_KD = 0.125f; // Derivative gain

// PidService pid(250, 150, 0.125);
PidService pid(PID_KP, PID_KI, PID_KD);

// Status
message_control_status lastMsg = {0, 0, 0, PID_KP, PID_KI, PID_KD};
ModeTypeTranslation current_mode = ModeTypeTranslation::MODE_WAR;

extern "C" void app_main();

double normalize(double x, double old_min, double old_max, double new_min, double new_max) {
    return new_min + (x - old_min) * (new_max - new_min) / (old_max - old_min);
}

bool messageChanged(const message_control_status &msg)
{
    return (lastMsg.move_x != msg.move_x || lastMsg.move_y != msg.move_y ||
            lastMsg.param_p != msg.param_p || lastMsg.param_i != msg.param_i ||
            lastMsg.param_d != msg.param_d || lastMsg.mode != msg.mode);
}

void doWhenMove(message_control_status msg)
{
    // if move_x is different than 0, check if positive or negative and scale it to either [-MAX_CONTROL_RANGE, 0] or [0, MAX_CONTROL_RANGE]
    int move_x = 0;
    if (msg.move_x != 0) {
        move_x = (msg.move_x > 0) ? normalize(msg.move_x, 0, MAX_CONTROL_RANGE, 0, MAX_CONTROL_RANGE) : normalize(msg.move_x, -MAX_CONTROL_RANGE, 0, -MAX_CONTROL_RANGE, 0);
        turn = -(move_x)/MAX_CONTROL_RANGE;
    }
    else 
    {
        turn = 0.0f; // Reset turn if move_x is 0
    }
    // if move_y is different than 0, check if positive or negative and scale it to either [-MAX_CONTROL_RANGE, 0] or [0, MAX_CONTROL_RANGE]
    int move_y = 0;
    if (msg.move_y != 0) {
        move_y = (msg.move_y > 0) ? normalize(msg.move_y, 0, MAX_CONTROL_RANGE, 0, MAX_CONTROL_RANGE) : normalize(msg.move_y, -MAX_CONTROL_RANGE, 0, -MAX_CONTROL_RANGE, 0);
        deltaAlpha = -(move_y)/MAX_CONTROL_RANGE;
    }
    else
    {
        deltaAlpha = 0.0f; // Reset deltaAlpha if move_y is 0
    }

    // update pid
    pid.setKp(msg.param_p);
    pid.setKi(msg.param_i);
    pid.setKd(msg.param_d);

    ESP_LOGI(MESSAGE_TAG, "Move X: %d -> %d, Move Y: %d -> %d || Delta Alpha: %6lf - Turn: %6lf", msg.move_x, move_x, msg.move_y, move_y, deltaAlpha, turn);

    current_mode = static_cast<ModeTypeTranslation>(msg.mode);
}

static void recvcb(const esp_now_recv_info_t * esp_now_info, const uint8_t *data, int data_len)
{
    message_control_status msg = *(message_control_status*)&data[0];
    if (messageChanged(msg))
    {
        ESP_LOGI(MESSAGE_TAG, "Message changed. Mode: %d, Move X: %d, Move Y: %d, Param P: %3.0f, Param I: %3.0f, Param D: %.3f", 
            msg.mode, msg.move_x, msg.move_y, msg.param_p, msg.param_i, msg.param_d);
        lastMsg = msg; // Update last message
        doWhenMove(msg);
    }
}

void applyMode()
{
    switch (current_mode)
    {
        case ModeTypeTranslation::MODE_STANDING:
            // Apply standing mode settings
            expected_vertical = expectedVerticalStandingmode;
            servo.setPos(90);
            break;
        case ModeTypeTranslation::MODE_WAR:
            // Apply war mode settings
            expected_vertical = expectedVerticalWarmode;
            servo.setPos(0);
            break;
        default:
            break;
    }
}

void app_main(void)
{
    vTaskDelay(pdMS_TO_TICKS(100));

    // Robot parts
    MotorDefinition rightMotor;
    MotorDefinition leftMotor;
    PinGPIODefinition stby;

    Direction correctionDir = { X_Direction::X_CENTER, Y_Direction::Y_CENTER};

    // Initialize LibNow
    ESP_LOGI(LIBNOW_TAG, "Initializing LibNow...");
    libnow_init();
    libnow_addPeer(LibNowDst::DST_MANDO);
    esp_now_register_recv_cb(recvcb);
    ESP_LOGI(LIBNOW_TAG, "LibNow initialized");

    // Configuring motors
    ESP_LOGI(MAIN_TAG, "Configuring motors...");
    rightMotor = MotorDefinition(MOTOR_A_IN_1, MOTOR_A_IN_2, 0, 1, MOTOR_A_PWM, LEDC_CHANNEL_0, LEDC_SPEED_MODE, LEDC_TIMER_0);
    ESP_LOGI(MOTOR_TAG, "Right motor configured on GPIO %d and %d", MOTOR_A_IN_1, MOTOR_A_IN_2);
    leftMotor = MotorDefinition(MOTOR_B_IN_1, MOTOR_B_IN_2, 1, 0, MOTOR_B_PWM, LEDC_CHANNEL_1, LEDC_SPEED_MODE, LEDC_TIMER_1);
    ESP_LOGI(MOTOR_TAG, "Left motor configured on GPIO %d and %d", MOTOR_B_IN_1, MOTOR_B_IN_2);
    stby = PinGPIODefinition(STBY, GPIO_MODE_OUTPUT, GPIO_PULLDOWN_DISABLE);

    robot = RobotDefinition(leftMotor, rightMotor, stby, LEFT_MOTOR_CORRECTION, RIGHT_MOTOR_CORRECTION);
    robot.Configure();

    ESP_LOGI(MOTOR_TAG, "Motors configured");
    ESP_LOGI(MAIN_TAG, "GPIOs configured");

    // Initialize servo
    ESP_LOGI(SERVO_TAG, "Initializing servo...");
    servo.initHw(servo_pin); // GPIO 25 for servo control
    servo.calibrate(409, 2048); // Calibrate servo with min and max duty cycle
    applyMode(); // Apply initial mode settings
    ESP_LOGI(SERVO_TAG, "Servo initialized");

    // Configuring bmi
    ESP_LOGI(IMU_TAG, "Configuring BMI160 IMU...");
    Bmi160SpiConfig config = {
        .spidev = SPI3_HOST,
        .mosi = MOSI_PIN,
        .miso = MISO_PIN,
        .sclk = SCLK_PIN,
        .cs   = CS_PIN,
        .speed= 4*1000*1000
    };

    if (imu.init(config) != BMI160_OK)
    {
        ESP_LOGE(IMU_TAG, "Failed to initialize bmi160 device");
    }
    else
    {
        Bmi160Data accelData, gyroData;
        
        deltaAlpha = 0.0f;
        turn = 0.0f;

        // start calibration
        ESP_LOGI(IMU_TAG, "Starting calibration...");
        float gyroOffsetX = 0.0f, gyroOffsetY = 0.0f, gyroOffsetZ = 0.0f;

        // collect data
        const int num_samples = 50;
        for (int i = 0; i < num_samples; i++)
        {
            imu.getData(accelData, gyroData);
            gyroOffsetX += gyroData.adj_data.x;
            gyroOffsetY += gyroData.adj_data.y;
            gyroOffsetZ += gyroData.adj_data.z;
            vTaskDelay(pdMS_TO_TICKS(10));
        }

        // normalize
        gyroOffsetX /= num_samples;
        gyroOffsetY /= num_samples;
        gyroOffsetZ /= num_samples;
        ESP_LOGI(IMU_TAG, "Calibration complete. Offsets: x: %f y: %f z: %f", gyroOffsetX, gyroOffsetY, gyroOffsetZ);

        float alpha = 0.0f; // [degree]
        float factor = 0.985f;
        float lastTime = 0.0f;
        float dt;
        float motorSpeed, prev_motor = 0;

        float p,i,d;

        // flattern data
        gyroData.adj_data.x -= gyroOffsetX;
        gyroData.adj_data.y -= gyroOffsetY;
        gyroData.adj_data.z -= gyroOffsetZ;

        // float initAccelX = accel_data.adj_data.x;
        float initAccelY = 0 - initAccelYCorrection;// axis Y has to be zeroed
        float initAccelZ = 1 - initAccelZCorrection;// axis Z has to be 1.0

        ESP_LOGI(IMU_TAG, "Initial gyro data: x: %f y: %f z: %f", gyroData.adj_data.x, gyroData.adj_data.y, gyroData.adj_data.z);
        ESP_LOGI(IMU_TAG, "Initial accel data: x: %f y: %f z: %f", accelData.adj_data.x, accelData.adj_data.y, accelData.adj_data.z);
        
        // first lecture
        imu.getData(accelData, gyroData);
        lastTime = gyroData.adj_data.sensortime;
        alpha = atan2f(accelData.adj_data.z + initAccelZ, accelData.adj_data.y + initAccelY) * 180.0f / M_PI;        

        ESP_LOGI(IMU_TAG, "Initial alpha: %6f", alpha);

        for (;;)
        {
            
            // Apply message control data
            applyMode();

            // get bmi data
            imu.getData(accelData, gyroData);

            // flattern data
            gyroData.adj_data.x -= gyroOffsetX;
            gyroData.adj_data.y -= gyroOffsetY;
            gyroData.adj_data.z -= gyroOffsetZ;

            dt = (gyroData.adj_data.sensortime - lastTime) / 1000.0f;
            lastTime = gyroData.adj_data.sensortime;

            float firstPart = alpha - gyroData.adj_data.x * dt;
            float secondPart = atan2f(accelData.adj_data.z + initAccelZ, accelData.adj_data.y + initAccelY) * 180.0f / M_PI;
            alpha = firstPart * factor + secondPart * (1 - factor);

            float alphaError = expected_vertical - alpha - deltaAlpha * (deltaAlpha < 0.0f ? DELTA_FORWARD_ALPHA_RANGE : DELTA_BACKWARD_ALPHA_RANGE);
            motorSpeed = pid.update(alphaError, dt);
            pid.getLastPid(p, i, d);

            motorSpeed = prev_motor * 0.1 + motorSpeed * 0.9;
            prev_motor = motorSpeed;

            correctionDir = { X_Direction::X_CENTER, Y_Direction::Y_CENTER };
            if (alphaError != 0){
                correctionDir.vertical = alphaError > 0 ? Y_Direction::FORWARD : Y_Direction::BACKWARD;
            }

            if (turn < 0.0f){
                correctionDir.horizontal = X_Direction::RIGHT;
            } else if (turn > 0.0f){
                correctionDir.horizontal = X_Direction::LEFT;
            } else {
                correctionDir.horizontal = X_Direction::X_CENTER;
            }

            motorSpeed = -(motorSpeed + (fabs(turn * TURN_RANGE)));

            int32_t speedForMotor = 0;
            if (motorSpeed > 1023)
                speedForMotor = 1023;
            else if (motorSpeed < -1023)
                speedForMotor = -1023;
            else
                speedForMotor = static_cast<int32_t>(motorSpeed);

            if (fabs(speedForMotor) < BASE_SPEED && correctionDir.horizontal == X_Direction::X_CENTER){
                ESP_LOGI(MOTOR_TAG, "Speed too low: %6ld at angle %6f", speedForMotor, alpha);
                robot.Stop(); // Stop the robot if speed is too low
                vTaskDelay(pdMS_TO_TICKS(20));
                continue; // Skip if speed is too low
            }

            ESP_LOGI(CONTROL_TAG, "Turn: %6f - Delta Alpha: %6f - Correction Dir: %s/%s", 
                turn, deltaAlpha, robot.X_DirectionToString(correctionDir.horizontal), robot.Y_DirectionToString(correctionDir.vertical));

            ESP_LOGI(ACTION_TAG, "Expected vertical: %6f - Alpha: %6f - Error: %6f - Direction: %s - Speed: %6ld", expected_vertical, alpha, alphaError, robot.Y_DirectionToString(correctionDir.vertical), speedForMotor);
            robot.Drive(correctionDir, speedForMotor);

            vTaskDelay(pdMS_TO_TICKS(20));
        }
    }
}

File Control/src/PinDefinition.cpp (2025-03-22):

#include <driver/gpio.h>
#include "driver/ledc.h"
#include "PinDefinition.h"
#include <esp_log.h>

PinGPIODefinition::PinGPIODefinition(){};

PinGPIODefinition::PinGPIODefinition(gpio_num_t pin, gpio_mode_t mode, gpio_pulldown_t pull_down)
{
    // printf("Creating pingpio %d\n", pin);
    this->pin = pin;
    this->mode = mode;
    this->pull_down = pull_down;
};

void PinGPIODefinition::Configure()
{
    // printf("Configuring pin %d\n", pin);
    gpio_config_t io_conf;
    io_conf.intr_type = GPIO_INTR_DISABLE;
    io_conf.mode = mode;
    io_conf.pin_bit_mask = 1ULL << pin;
    io_conf.pull_down_en = pull_down;
    io_conf.pull_up_en = GPIO_PULLUP_DISABLE;
    gpio_config(&io_conf);
};

PinPWMDefinition::PinPWMDefinition(){};

PinPWMDefinition::PinPWMDefinition(gpio_num_t pin, ledc_channel_t channel, ledc_mode_t speed_mode, ledc_timer_t timer)
{
    // printf("Creating pinpwm %d\n", pin);
    this->pin = pin;
    this->channel = channel;
    this->speed_mode = speed_mode;
    this->timer = timer;
};

void PinPWMDefinition::Configure()
{
    // printf("Configuring pin %d\n", pin);
    ledc_timer_config_t ledc_timer_motor;
    ledc_timer_motor.duty_resolution = LEDC_TIMER_10_BIT;
    ledc_timer_motor.freq_hz = 20000; // Set output frequency at 1 kHz
    ledc_timer_motor.speed_mode = speed_mode;
    ledc_timer_motor.timer_num = timer;
    ledc_timer_motor.clk_cfg = LEDC_AUTO_CLK;
    ledc_timer_motor.deconfigure = 0;
    ESP_ERROR_CHECK(ledc_timer_config(&ledc_timer_motor));

    ledc_channel_config_t ledc_channel_motor;
    ledc_channel_motor.channel = channel;
    ledc_channel_motor.duty = 0;
    ledc_channel_motor.gpio_num = pin;
    ledc_channel_motor.speed_mode = speed_mode;
    ledc_channel_motor.timer_sel = timer;
    ledc_channel_motor.intr_type = LEDC_INTR_DISABLE;
    ledc_channel_motor.flags.output_invert = 0;
    ledc_channel_motor.hpoint = 0;
    ESP_ERROR_CHECK(ledc_channel_config(&ledc_channel_motor));
};

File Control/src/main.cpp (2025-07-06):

#include <freertos/FreeRTOS.h>
#include <freertos/task.h>
#include <driver/gpio.h>
#include <driver/ledc.h>
#include <esp_adc/adc_oneshot.h>
#include <esp_adc/adc_cali.h>
#include <esp_adc/adc_cali_scheme.h>
#include <esp_log.h>
#include <esp_err.h>
#include <memory>
#include <string.h>

#include <ssd1306.h>
#include <font8x8_basic.h>

#include "libnow.h"

#include "ControlStatus.h"
#include "PinDefinition.h"

// Logger tag for ESP-IDF logging
static const char *MAIN_TAG = "main_log";
static const char *MODE_TAG = "mode_log";
static const char *ADC_TAG = "adc_log";
static const char *BLOCK_TAG = "block_log";
static const char *SCREEN_TAG = "ssd1306_log";
static const char *JOYSTICK_TAG = "joystick_log";
static const char *REPORT_TAG = "report_log";
static const char *LIBNOW_TAG = "libnow_log";

// Libnow
#define MAC_MANDO { 0x3c, 0x84, 0x27, 0xad, 0xe5, 0x18 }

// Led
constexpr gpio_num_t LED_PIN = GPIO_NUM_4;
PinGPIODefinition led;
uint32_t led_value = 0;

// Push buttons
constexpr gpio_num_t MODE_PIN = GPIO_NUM_2;
PinGPIODefinition mode;

constexpr gpio_num_t BLOCK_PIN = GPIO_NUM_8;
PinGPIODefinition block;

// Control
constexpr gpio_num_t POT_PIN = GPIO_NUM_3;
constexpr adc_channel_t POT_ADC_CHANNEL = ADC_CHANNEL_3; // GPIO03
constexpr adc_atten_t ADC_ATTEN = ADC_ATTEN_DB_12; // 0-3.1V range

static bool example_adc_calibration_init(adc_unit_t unit, adc_channel_t channel, adc_atten_t atten, adc_cali_handle_t *out_handle);
static void example_adc_calibration_deinit(adc_cali_handle_t handle);

// Status
ControlStatus current_status;

// Screen
SSD1306_t oled_dev;
char lock_display = {0}; // Single reusable buffer
char display_buffer[16] = {0};  // Single reusable buffer

// PID defaults
constexpr float DEFAULT_P = 250;
constexpr float DEFAULT_I = 125;
constexpr float DEFAULT_D = 0.125;

// JOYSTICK
constexpr adc_channel_t JOYSTICK_CHANNEL_X = ADC_CHANNEL_0; // GPIO00
constexpr adc_channel_t JOYSTICK_CHANNEL_Y = ADC_CHANNEL_1; // GPIO01
constexpr gpio_num_t JOYSTICK_BUTTON_PIN = GPIO_NUM_9;
PinGPIODefinition param;

void update_movement_display()
{
    // Line 3: Joystick Values
    memset(display_buffer, 0, sizeof(display_buffer));
    snprintf(display_buffer, sizeof(display_buffer), "X:%5d Y:%5d", current_status.current_X, current_status.current_Y);
    ssd1306_display_text(&oled_dev, 3, display_buffer, 16, false);
}

void update_display() {
    ssd1306_clear_screen(&oled_dev, false);

    // Line 0: Mode - Param
    memset(display_buffer, 0, sizeof(display_buffer));
    lock_display = current_status.current_lock == LockType::LOCKED ? 'L' : 'U';//static_cast<char>(0x1F512) : static_cast<char>(0x1F513);
    snprintf(display_buffer, sizeof(display_buffer), "%s - %s (%c)", 
             current_status.ModeToString(), current_status.ParamToString(), lock_display);
    ssd1306_display_text(&oled_dev, 0, display_buffer, 16, false);

   // Line 2: PID Headers
   memset(display_buffer, 0, sizeof(display_buffer));
   snprintf(display_buffer, sizeof(display_buffer), "%3s %3s %4s", "P", "I", "D");
   ssd1306_display_text(&oled_dev, 1, display_buffer, 16, false);

    // Line 2: PID Values
    memset(display_buffer, 0, sizeof(display_buffer));
    snprintf(display_buffer, sizeof(display_buffer), "%3.0f %3.0f %.3f", current_status.current_P, current_status.current_I, current_status.current_D);
    ssd1306_display_text(&oled_dev, 2, display_buffer, 16, false);

    // Line 3: Joystick Values
    update_movement_display();
}

void update_pid(int orientation)
{
    switch(current_status.current_param)
    {
        case ParamType::P:
            current_status.current_P += orientation == 1 ? 5 : -5;
            if (current_status.current_P < 0) current_status.current_P = 0;
            break;
        case ParamType::I:
            current_status.current_I += orientation == 1 ? 1 : -1;
            if (current_status.current_I < 0) current_status.current_I = 0;
            break;
        case ParamType::D:
            current_status.current_D += orientation == 1 ? .05 : -.05;
            if (current_status.current_D < 0) current_status.current_D = 0;
            break;
    }
}

extern "C" void app_main();

void app_main(void)
{
    vTaskDelay(pdMS_TO_TICKS(300));
    ESP_LOGI(MAIN_TAG, "Starting application...");

    // OLED
    ESP_LOGI(SCREEN_TAG, "Initializing SSD1306 OLED display...");
    ESP_LOGI(SCREEN_TAG, "INTERFACE is i2c");
    ESP_LOGI(SCREEN_TAG, "CONFIG_SDA_GPIO=%d",CONFIG_SDA_GPIO);
    ESP_LOGI(SCREEN_TAG, "CONFIG_SCL_GPIO=%d",CONFIG_SCL_GPIO);
    ESP_LOGI(SCREEN_TAG, "CONFIG_RESET_GPIO=%d",CONFIG_RESET_GPIO);
    ESP_LOGI(SCREEN_TAG, "Panel is 128x32");

    i2c_master_init(&oled_dev, CONFIG_SDA_GPIO, CONFIG_SCL_GPIO, CONFIG_RESET_GPIO);

    ssd1306_init(&oled_dev, 128, 32);
    ssd1306_clear_screen(&oled_dev, false);
    ssd1306_contrast(&oled_dev, 0xff);
    char starting_text[] = "STARTING...";
    ssd1306_display_text(&oled_dev, 0, starting_text, 9, false);

    ESP_LOGI(SCREEN_TAG, "SSD1306 initialized");

    // GPIOs
    ESP_LOGI(MAIN_TAG, "Configuring GPIOs...");
    // Configuring LED PIN
    led = PinGPIODefinition(LED_PIN, GPIO_MODE_OUTPUT, GPIO_PULLDOWN_DISABLE);
    led.Configure();
    ESP_LOGI(MODE_TAG, "Led configured on GPIO %d", LED_PIN);

    // Configuring MODE PIN
    mode = PinGPIODefinition(MODE_PIN, GPIO_MODE_INPUT, GPIO_PULLDOWN_DISABLE);
    mode.Configure();
    ESP_LOGI(MODE_TAG, "Mode configured on GPIO %d", MODE_PIN);

    // Configuring LOCK PIN
    block = PinGPIODefinition(BLOCK_PIN, GPIO_MODE_INPUT, GPIO_PULLDOWN_DISABLE);
    block.Configure();
    ESP_LOGI(BLOCK_TAG, "Block configured on GPIO %d", BLOCK_PIN);

    ESP_LOGI(MAIN_TAG, "GPIOs configured");

    // Configure base ADC
    ESP_LOGI(ADC_TAG, "Configuring ADC...");
    adc_oneshot_unit_handle_t adc1_handle;
    adc_oneshot_unit_init_cfg_t init_config1 = {
        .unit_id = ADC_UNIT_1,
        .clk_src = ADC_DIGI_CLK_SRC_DEFAULT,
        .ulp_mode = ADC_ULP_MODE_DISABLE,
    };
    ESP_ERROR_CHECK(adc_oneshot_new_unit(&init_config1, &adc1_handle));

    // Configure POT ADC
    adc_oneshot_chan_cfg_t pot_config = {
        .atten = ADC_ATTEN,
        .bitwidth = ADC_BITWIDTH_DEFAULT,
    };
    ESP_ERROR_CHECK(adc_oneshot_config_channel(adc1_handle, POT_ADC_CHANNEL, &pot_config));
    adc_cali_handle_t adc1_cali_control_handle = NULL;
    bool do_calibration1_control = example_adc_calibration_init(ADC_UNIT_1, POT_ADC_CHANNEL, ADC_ATTEN, &adc1_cali_control_handle);
    
    int pid_orientation = 0;
    int raw_value;
    int voltage_value;
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

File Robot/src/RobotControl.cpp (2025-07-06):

#include "RobotControl.h"
#include <array>

RobotDefinition::RobotDefinition(){};

RobotDefinition::RobotDefinition(MotorDefinition leftMotor, MotorDefinition rightMotor, PinGPIODefinition stby, int leftCorrection, int rightCorrection)
    : leftMotor(leftMotor), rightMotor(rightMotor), stby(stby), leftCorrection(leftCorrection), rightCorrection(rightCorrection) {}

constexpr std::array<const char*, 3> X_DirectionStrings = { "Right", "Center", "Left" };
constexpr std::array<const char*, 3> Y_DirectionStrings = { "Forward", "Center", "Backward" };

const char* RobotDefinition::X_DirectionToString(X_Direction dir)
{
    return X_DirectionStrings.at(static_cast<size_t>(dir));
};

const char* RobotDefinition::Y_DirectionToString(Y_Direction dir)
{
    return Y_DirectionStrings.at(static_cast<size_t>(dir));
}

void RobotDefinition::Configure()
{
    // Configure the motors
    this->rightMotor.Configure();
    this->leftMotor.Configure();

    // Configure STBY pin as output
    this->stby.Configure();
    gpio_set_level(this->stby.Pin(), 1); // Set STBY high to enable the motors
}

void RobotDefinition::Drive(Direction dir, int speed)
{
    if (speed < 0)
    {
        speed = -speed; // Make speed positive for driving
    }

    if (dir.horizontal == RIGHT)
    {
        if (dir.vertical == FORWARD)
        {
            this->rightMotor.Drive(speed / 2, this->rightCorrection);
            this->leftMotor.Drive(speed, this->leftCorrection);
        }
        else if (dir.vertical == BACKWARD)
        {
            this->rightMotor.Drive(-speed / 2, this->rightCorrection);
            this->leftMotor.Drive(-speed, this->leftCorrection);
        }
        else if (dir.vertical == Y_CENTER)
        {
            this->rightMotor.Stop();
            this->leftMotor.Drive(speed, this->leftCorrection);
        }
    }
    else if (dir.horizontal == X_CENTER)
    {
        if (dir.vertical == FORWARD)
        {
            this->rightMotor.Drive(speed, this->rightCorrection);
            this->leftMotor.Drive(speed, this->leftCorrection);
        }
        else if (dir.vertical == BACKWARD)
        {
            this->rightMotor.Drive(-speed, this->rightCorrection);
            this->leftMotor.Drive(-speed, this->leftCorrection);
        }
        else if (dir.vertical == Y_CENTER)
        {
            // Stop both motors
            this->rightMotor.Stop();
            this->leftMotor.Stop();
        }
    }
    else if (dir.horizontal == LEFT)
    {
        if (dir.vertical == FORWARD)
        {
            this->rightMotor.Drive(speed, this->rightCorrection);
            this->leftMotor.Drive(speed / 2, this->leftCorrection);
        }
        else if (dir.vertical == BACKWARD)
        {
            this->rightMotor.Drive(-speed, this->rightCorrection);
            this->leftMotor.Drive(-speed / 2, this->leftCorrection);
        }
        else if (dir.vertical == Y_CENTER)
        {
            this->rightMotor.Drive(-speed, this->rightCorrection);
            this->leftMotor.Stop();
        }
    }
}

void RobotDefinition::Stop()
{
    this->rightMotor.Stop();
    this->leftMotor.Stop();
}

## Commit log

2025-01-11 added doc and i2c sample
2025-01-17 added sample code for 04-bmi160-spi
2025-01-17 added schema for bmi160
    [04-bmi16-schema.fzz]
2025-01-19 improved sample day 4
2025-02-08 added servo liibrary con basic functionality
2025-02-09 adjusted config for different servos
2025-02-28 added docs for bmi160 and servo. added motorcontrol library
    [05-servo-schema.fzz]
2025-02-28 added motor driver schematic
    [06-motor-driver.fzz]
2025-03-01 working on motor driver
2025-03-01 fix ledc configure not initialized
    [PinDefinition.cpp, main.cpp]
2025-03-02 added base sample for ky-023
    [07-ky-023.fzz]
2025-03-02 added main schema
    [main-schema.fzz]
2025-03-15 fixes main schema and code
    [main-schema.fzz]
2025-03-15 working on correction of angle
    [main.cpp]
2025-03-15 adjusting pid
2025-03-16 fixing pid and calibration
    [PinDefinition.cpp, bmi160_wrapper.cpp, main.cpp]
2025-03-16 fixes pid + motorcontrol
    [main.cpp]
2025-03-22 added motor drive corrections and inverted pindefinition output
    [PinDefinition.cpp, main.cpp]
2025-03-22 splittet robot-control projects. updated readme with schema for robot
    [04-bmi16-schema.fzz, 05-servo-schema.fzz, 06-motor-driver.fzz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]
2025-03-30 updated control schema. added mode and param logic
    [main-schema.fzz]
2025-04-13 added ssd1306 display and pid control
2025-04-14 refactor adc, added joystick logic
2025-04-15 joystick logic and display of values
    [main-schema.fzz]
2025-04-16 calibration of potentiometer, refactor adc
2025-06-27 calibration adjustments
2025-06-27 more adjustments calibration
2025-07-02 fix: pid and main logic for stabilisation
    [main.cpp]
2025-07-03 fix: pid setup corrections
    [main.cpp]
2025-07-04 Update main.cpp
    flattern gyro data
2025-07-04 fix: initial calibration
2025-07-04 fix: more adjustments initial calibration
    [main.cpp]
2025-07-05 added 3d-design, more init calibration
    [Equili-bot-ista.3mf]
2025-07-06 more initial calibration
2025-07-06 pid adjustments
    [Equili-bot-ista.3mf]
2025-07-07 3d design and robot init calibration
    [Equili-bot-ista.3mf]
2025-07-07 servo: added basic servo control mode
2025-07-08 initial calibration two modes
2025-07-08 deactivated brown-out detector. fixed control messaging
    [main.cpp]
2025-07-09 initial calibrations
2025-07-11 3d control design
    [Control.3mf]
2025-07-11 3d control update
    [Control.3mf]
2025-07-12 updated 3d control
    [Control.3mf]
2025-07-12 finished init calibration and documentation
